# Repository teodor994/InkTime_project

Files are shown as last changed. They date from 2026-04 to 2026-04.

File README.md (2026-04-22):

<h1 align="center">InkTime Watch</h1>

<br>
<br>

This document presents the design and implementation details of the InkTime smartwatch project, covering both the hardware architecture and mechanical integration.

In the following sections, you will find comprehensive documentation including the schematic, PCB layout, component selection, and 3D assembly of the device.

<br> 

## Block Diagram

```text

                                +----------------------+
                                |        USB-C         |
                                |   Power / USB Data   |
                                +----------+-----------+
                                           |
                                           v
                                +----------------------+
                                |   ESD Protection     |
                                |    USBLC6-2SC6Y      |
                                +----------+-----------+
                                           |
                                           v
                                +----------------------+
                                |   Li-Po Charger      |
                                |    BQ25180YBGR       |
                                +----+------------+----+
                                     |            |
                                     |            +--------------------+
                                     |                                 |
                                     v                                 v
                           +-------------------+             +-------------------+
                           |   Li-Po Battery   |             |   Fuel Gauge      |
                           |     LP502030      |<-- I2C ---> |    MAX17048       |
                           +---------+---------+             +-------------------+
                                     |
                                     v
                           +-------------------+
                           | Buck-Boost DC/DC  |
                           |    RT6160AWSC     |
                           +---------+---------+
                                     |
                                   3V3 / VREG
                                     |
        +----------------------------+------------------------------+
        |                            |                              |
        v                            v                              v
+---------------+          +-------------------+          +-------------------+
|   nRF52840    |<--I2C--->|      BMA421       |<--I2C--->|     DRV2605       |
|   BLE MCU     |          |       IMU         |          |   Haptic Driver   |
+-------+-------+          +-------------------+          +---------+---------+
        |                                                              |
        | SPI + GPIO                                                    v
        v                                                      +----------------+
+-------------------+                                          | Vibration Motor|
| 1.54" E-Paper     |                                          |     (Shaker)   |
| via FPC Connector |                                          +----------------+
+-------------------+
        |
        +--> Dedicated E-Paper Power Stage:
             MOSFETs + Schottky Diodes + Inductors + Capacitors

```

## Hardware Functionality

###  Microcontroller

The system is built around a Nordic **nRF52840** SoC  
*(Arm Cortex-M4F @ 64 MHz, 1 MB Flash, 256 kB RAM)*.

This component was chosen because it integrates:
- a **2.4 GHz radio (Bluetooth Low Energy)**
- a **USB 2.0 full-speed controller**

 This allows both:
- wireless communication (BLE)
- USB-C data connectivity  

without requiring any external transceiver.

The MCU operates using two external crystals:
- **32 MHz HF crystal (XC1/XC2)** → CPU + radio
- **32.768 kHz LF crystal (XL1/XL2)** → RTC + low-power timing  

> Accurate timekeeping is critical for a watch, therefore the LFXO is mandatory.

An on-board **2.4 GHz chip antenna (2450AT18B100E)** is:
- placed at the edge of the PCB  
- isolated via a **ground keep-out zone**  

The antenna is connected to the `ANT` pin through a matching network.

---

### Display — E-Paper (SPI)

A reflective **e-paper display** is controlled via the SPI interface:

- `SCK` → P0.02  
- `MOSI` → P0.03  
- `CS` → P0.05  

Additional control signals:
- `EPD_DC` (P0.15) → command/data selection  
- `EPD_RST` (P0.16) → hardware reset  
- `EPD_BUSY` (P0.17) → busy status input  

The display is connected using a **24-pin FPC connector**.

#### Power Optimization
E-paper displays consume power **only during refresh**.

To optimize energy consumption:
- the display power rail is gated using a **PFET**
- controlled by `P1.01`

This allows:
- complete power shutdown between updates  
- significantly extended battery life (days instead of hours)

---

### IMU — BMA421 (I²C)

The **Bosch BMA421** accelerometer provides:
- 3-axis acceleration data  
- built-in **step counting functionality**

Connected via the shared I²C bus.

Interrupt lines:
- `IMU_INT1` → P0.08  
- `IMU_INT2` → P1.08  

These allow:
- wake-up from deep sleep  
- event-driven processing (no polling required)

---

### Haptics — DRV2605 (I²C)

The **TI DRV2605L** controls a vibration motor (LRA/ERM).

Key features:
- I²C configuration interface  
- internal ROM with predefined haptic effects  

The MCU only sends:
> “play effect N” commands  

instead of generating waveforms.

Control signal:
- `HAPTIC_EN` → P0.12  

Allows full shutdown of the driver when idle.

---

### Power Management  
**BQ25180 + MAX17048 + RT6160**

#### USB Input
- USB-C provides **5V input**
- protected by **USBLC6-2SC6Y (ESD protection)**
- includes **5.1 kΩ CC pull-down resistors** → device configured as sink

---

#### Battery Charging — BQ25180
Handles:
- Li-Po charging (CC/CV)
- power path management (USB ↔ battery switching)

Communication:
- I²C interface
- interrupt line: `PMIC_INT` → P0.11  

---

#### Voltage Regulation — RT6160
- Buck-boost converter generating stable **3.3V (VREG)**

Why buck-boost:
- battery range: **3.0V – 4.2V**
- ensures stable output across full discharge cycle

---

#### Fuel Gauge — MAX17048
Provides:
- battery percentage
- voltage monitoring

Uses **ModelGauge algorithm**:
- no current sense resistor required

Communication:
- I²C interface  
- `ALERT` → P1.10 (threshold events)

---

### Inputs — Buttons

Three user buttons connected as:
- `P0.13`
- `P0.14`
- `P1.02`

Characteristics:
- active-low configuration  
- RC debounce  
- internal pull-ups used  

Support:
- GPIOTE interrupts  
- wake-up from System OFF

---

### Shared I²C Bus

All I²C peripherals share the same bus:

Devices:
- BMA421 (IMU)
- MAX17048 (fuel gauge)
- DRV2605L (haptics)
- BQ25180 (charger)

Bus lines:
- `SDA` → P0.06  
- `SCL` → P0.07  

Pull-ups:
- **3.3 kΩ to 3V3**

Operating mode:
- **400 kHz (Fast Mode)**

Sufficient for low-bandwidth sensor communication.

---

### Debug Interface

Programming and debugging via SWD:

- `SWDCLK`
- `SWDIO`
- optional `SWO` → P1.00  

Connector:
- **Tag-Connect TC2030 footprint**

Advantage:
- no bulky header required (important for wearable design)

---

### Expected Capabilities

Based on this hardware, the system supports:

- accurate timekeeping using RTC + LFXO  
- rendering UI on e-paper display  
- step detection & gesture sensing  
- haptic feedback via vibration motor  
- BLE communication with a smartphone  
- USB connectivity for power and data  
- real-time battery monitoring  

The design enables a **low-power wearable device** with multi-day battery life.

## Pinout Table

| Pin | Signal | Direction | Peripheral | Description |
|-----|---|---|---|---|
| P0.02 | SPI_SCK | Output | E-Paper Display | SPI clock |
| P0.03 | SPI_MOSI | Output | E-Paper Display | SPI data out |
| P0.05 | EPD_CS | Output | E-Paper Display | Chip select |
| P0.06 | SDA | Bidir | Fuel Gauge, Charger, IMU, Haptics | Shared I2C data |
| P0.07 | SCL | Output | Fuel Gauge, Charger, IMU, Haptics | Shared I2C clock |
| P0.08 | IMU_INT1 | Input | IMU (BMA421) | Interrupt line 1 |
| P0.11 | PMIC_INT | Input | Charger (BQ25180) | Fault/status interrupt |
| P0.12 | HAPTIC_EN | Output | Haptics (DRV2605) | Driver enable |
| P0.13 | — | Input | Button 1 | User button |
| P0.14 | — | Input | Button 2 | User button |
| P0.15 | EPD_DC | Output | E-Paper Display | Data/command select |
| P0.16 | EPD_RST | Output | E-Paper Display | Display reset |
| P0.17 | EPD_BUSY | Input | E-Paper Display | Busy status |
| P0.18 | RESET | Input | — | System reset |
| P1.00 | SWO | Output | Debug (pad) | SWD trace output |
| P1.01 | — | Output | EPD power gate | EPD power control |
| P1.02 | — | Input | Button 3 | User button |
| P1.08 | IMU_INT2 | Input | IMU (BMA421) | Interrupt line 2 |
| P1.10 | ALERT | Input | Fuel Gauge (MAX17048) | UV/OV alert |
| D+ | D+ | Bidir | USB-C connector | USB data+ |
| D− | D- | Bidir | USB-C connector | USB data− |
| XL1/XL2 | — | — | 32.768 kHz crystal | Low-frequency clock |
| XC1/XC2 | — | — | 32 MHz crystal | High-frequency clock |
| SWDCLK | SWDCLK | Input | Debug (pad) | SWD clock |
| SWDIO | SWDIO | Bidir | Debug (pad) | SWD data |
| ANT | RF | Output | 2.4 GHz antenna | Wireless antenna feed |

## Bill of Materials (BOM)

| Part Name | Qty | Link (Order + Datasheet) |
| :-- | :--: | :--: |
| NRF52840-QIAA-R7 | 1 | [Link](https://jlcpcb.com/partdetail/NordicSemicon-NRF52840_QIAAR7/C1851953) |
| BMA421 | 1 | [Link](https://jlcpcb.com/partdetail/BoschSensortec-BMA421/C5242966) |
| DRV2605YZFR | 1 | [Link](https://jlcpcb.com/partdetail/TexasInstruments-DRV2605YZFR/C81079) |
| BQ25180YBGR | 1 | [Link](https://jlcpcb.com/partdetail/TexasInstruments-BQ25180YBGR/C3682423) |
| MAX17048G+T10 | 1 | [Link](https://jlcpcb.com/partdetail/2777647-MAX17048GT10/C2682616) |
| RT6160AWSC | 1 | [Link](https://jlcpcb.com/partdetail/RichtekTech-RT6160AWSC/C7065276) |
| USBLC6-2SC6Y | 1 | [Link](https://jlcpcb.com/partdetail/TECHPUBLIC-USBLC62SC6Y/C5310974) |
| KH-TYPE-C-16P | 1 | [Link](https://jlcpcb.com/partdetail/Shenzhen_KinghelmElec-KH_TYPE_C16P/C709357) |
| 2450AT18B100E | 1 | [Link](https://jlcpcb.com/partdetail/JohansonDielectrics-2450AT18B100E/C2917717) |
| SI1308EDL-T1-GE3 | 1 | [Link](https://jlcpcb.com/partdetail/VishayIntertech-SI1308EDL_T1GE3/C469327) |
| DMG2305UX-7 | 1 | [Link](https://jlcpcb.com/partdetail/DiodesIncorporated-DMG2305UX7/C150470) |
| 5034802400 | 1 | [Link](https://jlcpcb.com/partdetail/MOLEX-5034802400/C122434) |
| EVPAKE31A | 3 | [Link](https://jlcpcb.com/partdetail/PANASONIC-EVPAKE31A/C569760) |
| NX2016SA-32MHZ-STD-CZS-5 | 1 | [Link](https://jlcpcb.com/partdetail/NDK-NX2016SA_32MHZ_STD_CZS5/C843260) |
| CM8V-T1A-32.768KHZ-9PF-20PPM-TB-QA | 1 | [Link](https://jlcpcb.com/partdetail/C5366546) |
| SDFL1608S100KTF | 1 | [Link](https://jlcpcb.com/partdetail/Sunlord-SDFL1608S100KTF/C1035) |
| SDCL1005C15NJTDF | 1 | [Link](https://jlcpcb.com/partdetail/Sunlord-SDCL1005C15NJTDF/C27143) |
| SDCL1005C3N9STDF | 1 | [Link](https://jlcpcb.com/partdetail/Sunlord-SDCL1005C3N9STDF/C14033) |
| FTC252012SR47MBCA | 1 | [Link](https://jlcpcb.com/partdetail/6763488-FTC252012SR47MBCA/C5832368) |
| 744043680 | 1 | [Link](https://jlcpcb.com/partdetail/WurthElektronik-744043680/C2045671) |
| MBR0530 | 3 | [Link](https://jlcpcb.com/partdetail/78464-MBR0530/C77336) |
| GRM033R61A104KE15D | 5 | [Link](https://jlcpcb.com/partdetail/MurataElectronics-GRM033R61A104KE15D/C76934) |
| GRM155R60J226ME11D | 2 | [Link](https://jlcpcb.com/partdetail/408393-GRM155R60J226ME11D/C415703) |
| GRM155R61H105KE05D | 9 | [Link](https://jlcpcb.com/partdetail/1609005-GRM155R61H105KE05D/C1518208) |
| GRM0335C1H1R0BA01D | 2 | [Link](https://jlcpcb.com/partdetail/MurataElectronics-GRM0335C1H1R0BA01D/C85893) |
| GRM0335C1H101JA01D | 1 | [Link](https://jlcpcb.com/partdetail/MurataElectronics-GRM0335C1H101JA01D/C76922) |
| CGA0402X5R475M250GT | 1 | [Link](https://jlcpcb.com/partdetail/HRE-CGA0402X5R475M250GT/C6119795) |
| CL05A475MP5NRNC | 5 | [Link](https://jlcpcb.com/partdetail/24469-CL05A475MP5NRNC/C23733) |
| CL05A105KA5NQNC | 6 | [Link](https://jlcpcb.com/partdetail/53938-CL05A105KA5NQNC/C52923) |
| CL05A106MQ5NUNC | 3 | [Link](https://jlcpcb.com/partdetail/16204-CL05A106MQ5NUNC/C15525) |
| CC0201KRX5R7BB473 | 1 | [Link](https://jlcpcb.com/partdetail/YAGEO-CC0201KRX5R7BB473/C505465) |
| 0201X104K100NT | 5 | [Link](https://jlcpcb.com/partdetail/270391-0201X104K100NT/C284966) |
| 0201WMF220KTEE | 1 | [Link](https://jlcpcb.com/partdetail/479910-0201WMF220KTEE/C473517) |
| 0201WMJ0000TEE | 3 | [Link](https://jlcpcb.com/partdetail/259867-0201WMJ0000TEE/C270337) |
| 0201WMJ0332TEE | 2 | [Link](https://jlcpcb.com/partdetail/259848-0201WMJ0332TEE/C270318) |
| 0201CG120J500NT | 4 | [Link](https://jlcpcb.com/partdetail/51400-0201CG120J500NT/C50391) |
| CR0201FH5101G | 2 | [Link](https://jlcpcb.com/partdetail/LIZElec-CR0201FH5101G/C100142) |
| CPF0201D10KC1 | 6 | [Link](https://jlcpcb.com/partdetail/TEConnectivity-CPF0201D10KC1/C4187156) |
| UCR006YVPFLR470 | 1 | [Link](https://jlcpcb.com/partdetail/ROHMSemicon-UCR006YVPFLR470/C2089071) |

## Design Details

### Schematic and Components

The reference schematic was carefully reviewed and validated against the datasheets of each individual component. Any inconsistencies identified during this process were analyzed and corrected, most of them originating from outdated reference designs used in the initial schematic.

---

### PCB Layout and Routing

The PCB was designed in accordance with the manufacturing constraints specified by JLCPCB for standard rigid PCB assembly.

A ground pour was implemented on the top layer and connected to the main ground plane using via stitching. Additional manual stitching was applied in sensitive areas, particularly around the antenna feed line, to improve signal integrity.

Teardrops were added to most trace junctions to enhance mechanical reliability. Due to limitations in Fusion when generating teardrops for off-grid or rotated components, some shapes—especially those near the MCU (placed at a 45-degree angle)—were manually refined to ensure proper geometry.

Given the limited available space and the minimum recommended silkscreen text size of 1 mm, an indexed labeling approach was used. Larger components, ICs, and important pads were labeled directly on the silkscreen, while smaller areas rely on the legend.

To ensure mechanical robustness, relatively large internal annular rings were maintained. As a consequence, certain unused pins of the MCU were masked to prevent unintended electrical connections with traces routed underneath.

VIA-in-pad (ViP) technology was used extensively for compact multi-pin SMD components. Any DRC warnings related to ViP clearances were manually reviewed and accepted where appropriate.

Special attention was given to spatial constraints such as:
- antenna keep-out zone
- crystal oscillator trace length
- maximizing distance between the IMU and the shaker motor

Additionally, all decoupling capacitors were placed as close as possible to their respective power pins.

The USB differential pair (D+ and D−) was routed carefully, maintaining approximately equal lengths and minimal spacing between the traces to preserve signal integrity.

---

### 3D Design

Accurate 3D models for all components were integrated into the PCB assembly in order to validate the mechanical design.

The complete enclosure assembly was analyzed to detect any potential mechanical interferences. A possible issue was identified regarding the battery height specified in its datasheet, as the available space in the lower part of the enclosure may be insufficient.

At this stage, the enclosure design was left unchanged, with the intention of validating this aspect during the physical prototyping phase.

## Renders

### PCB 2D
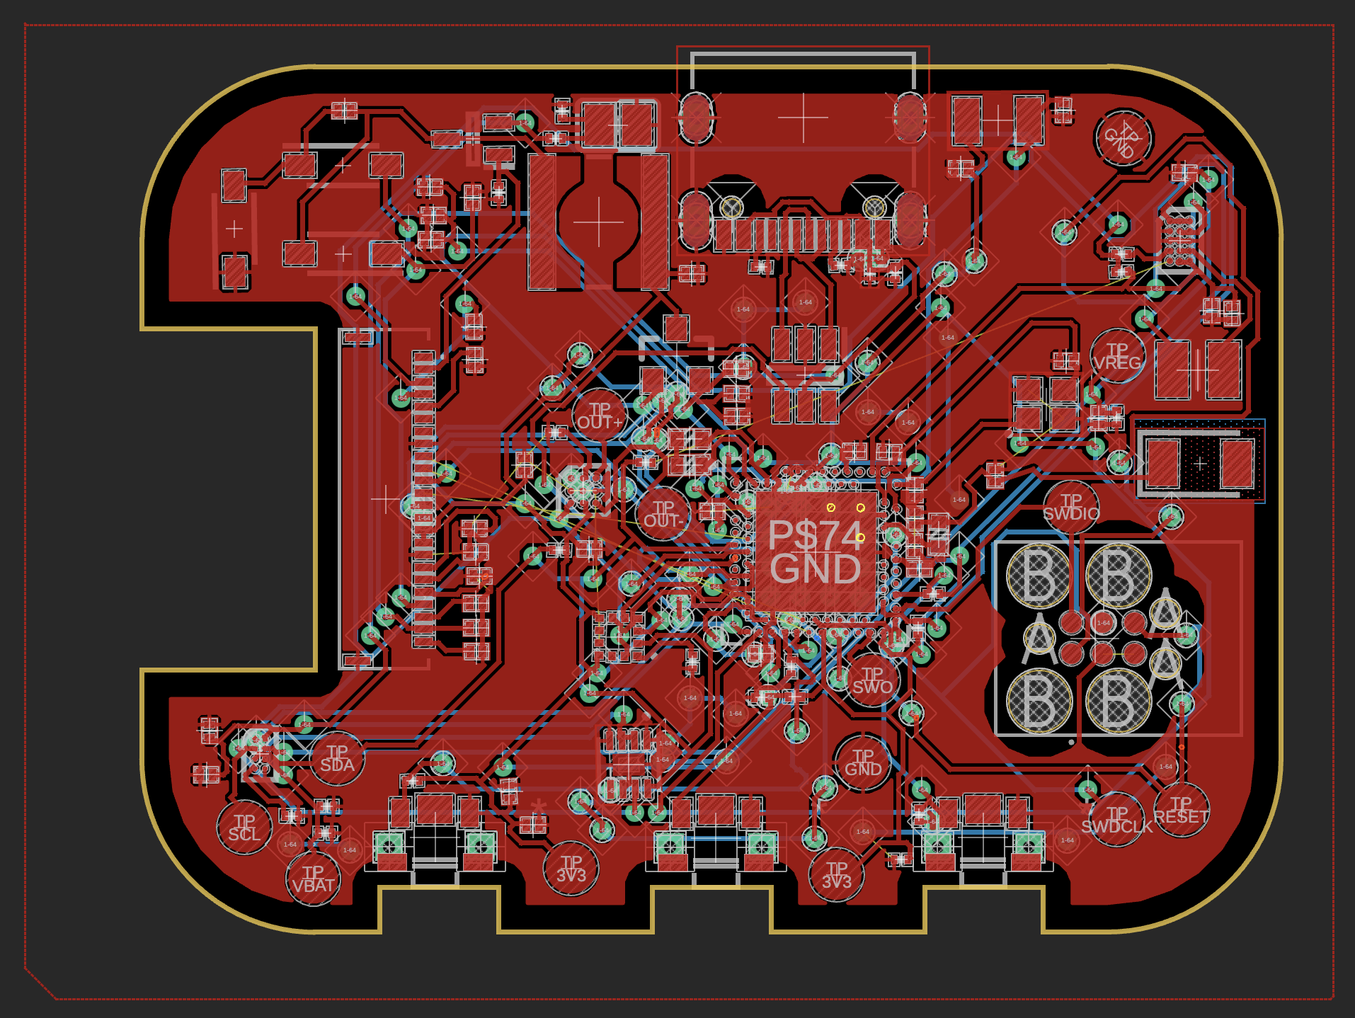
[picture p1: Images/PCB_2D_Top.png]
PCB_2D_Top

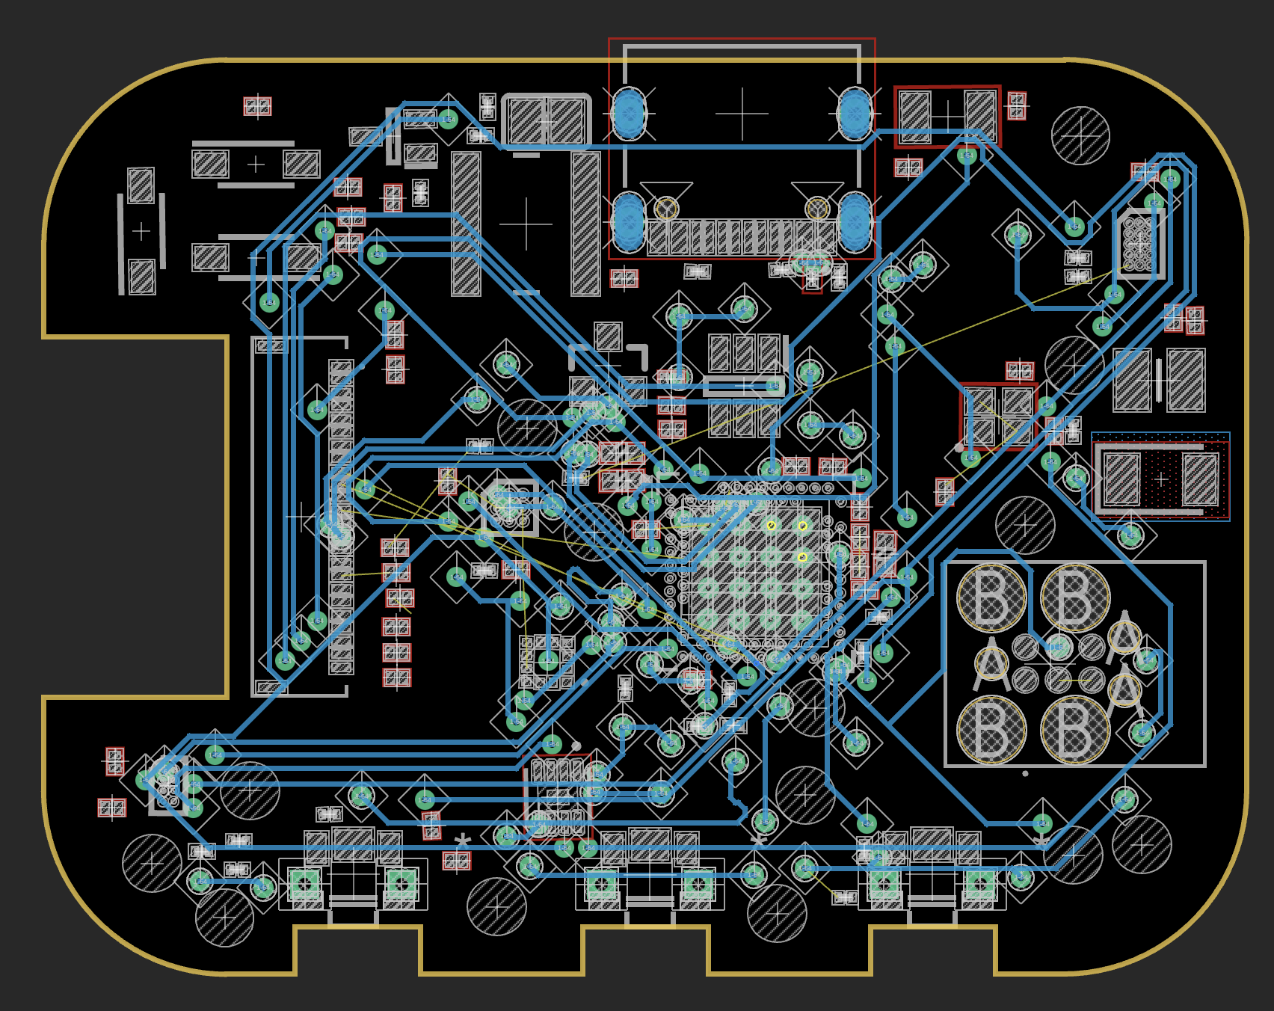
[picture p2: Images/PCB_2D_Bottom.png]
PCB_2D_Bottom


### PCB 3D
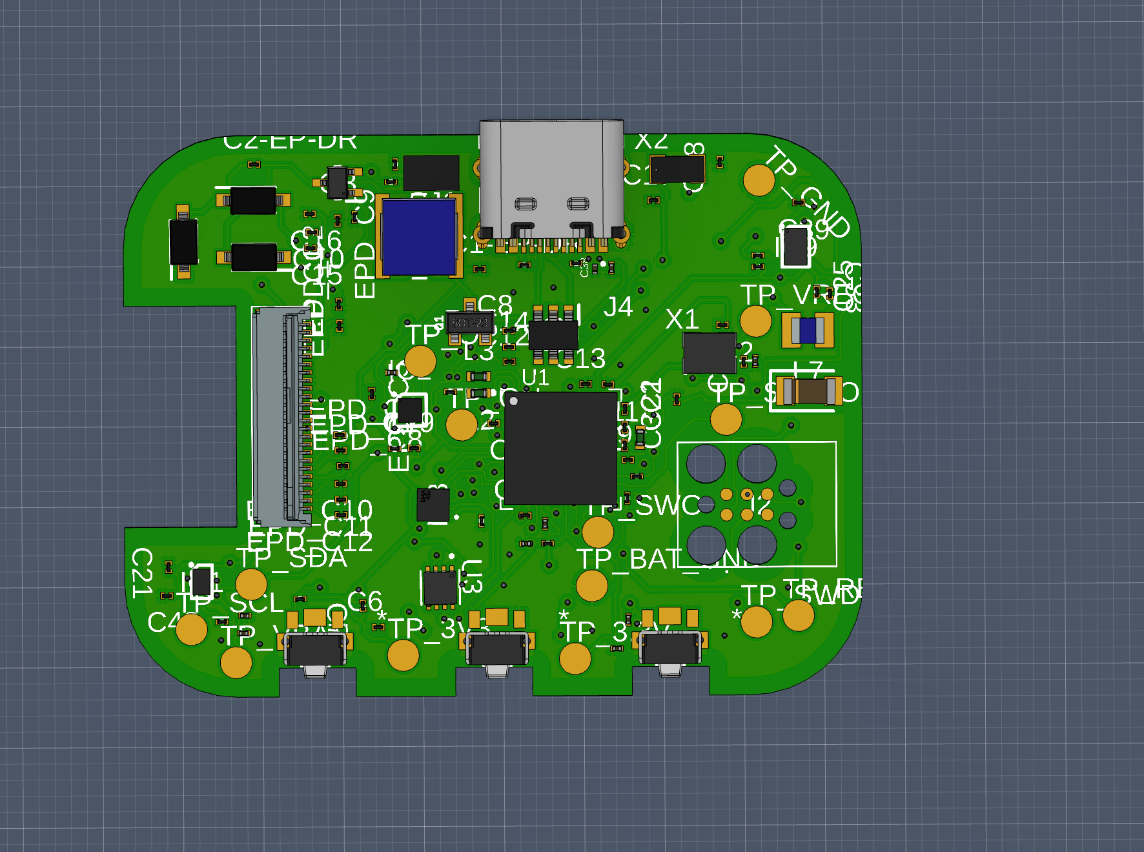
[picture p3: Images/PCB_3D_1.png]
PCB_3D_1

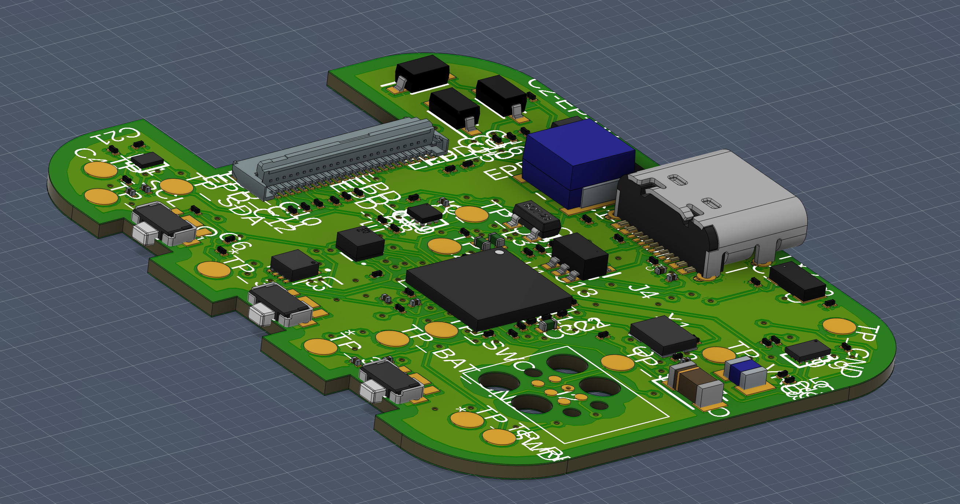
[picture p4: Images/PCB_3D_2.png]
PCB_3D_2


### Assembly
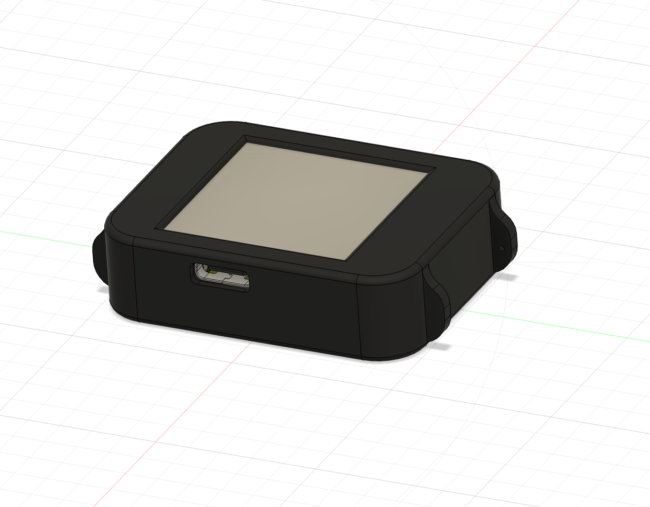
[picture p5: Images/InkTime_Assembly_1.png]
InkTime_Assembly_1

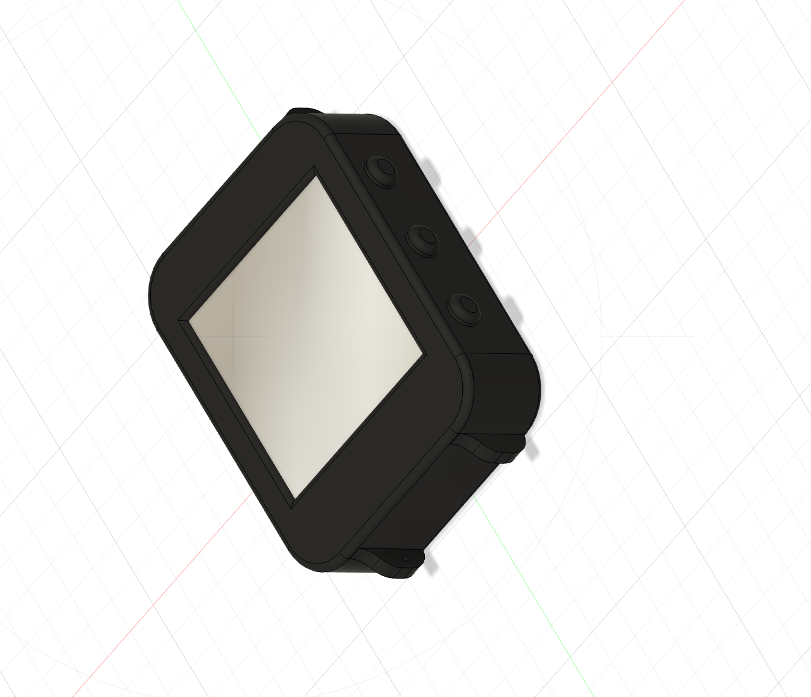
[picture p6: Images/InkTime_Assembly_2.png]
InkTime_Assembly_2


### Exploded View
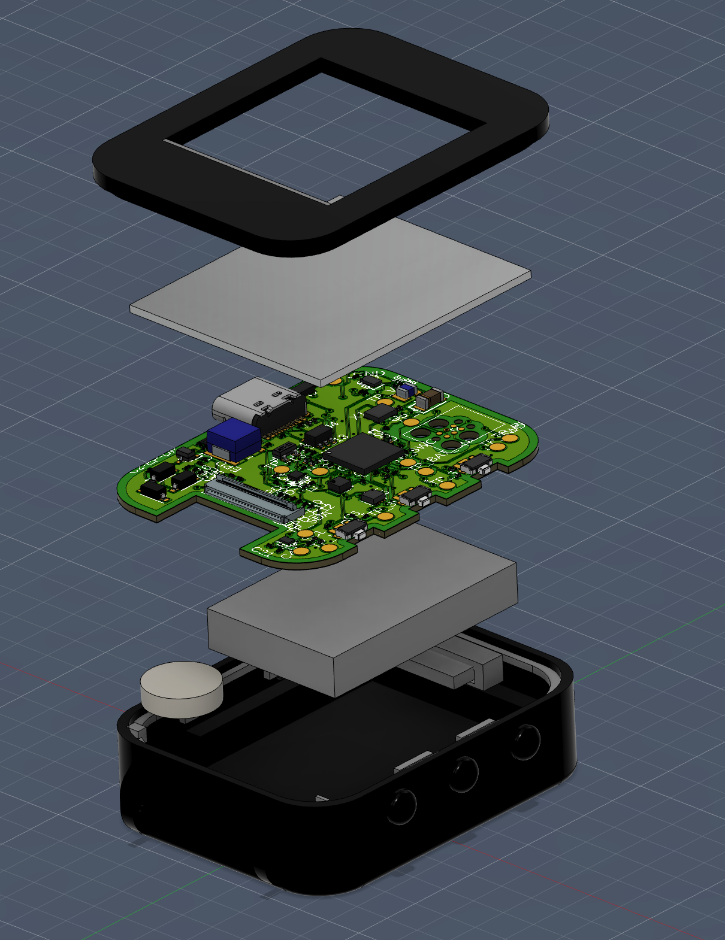
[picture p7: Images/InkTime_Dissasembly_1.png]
InkTime_Dissasembly_1

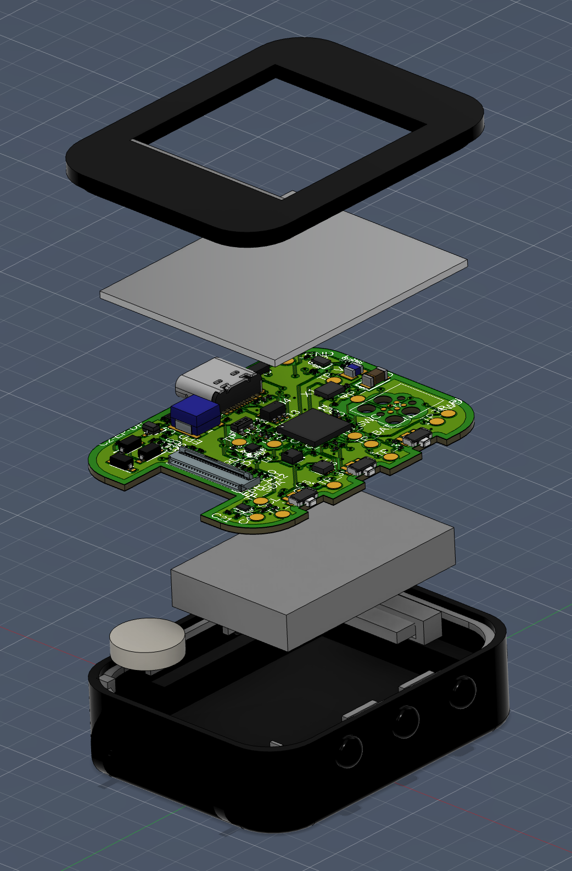
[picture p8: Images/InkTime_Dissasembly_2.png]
InkTime_Dissasembly_2


### Without Display
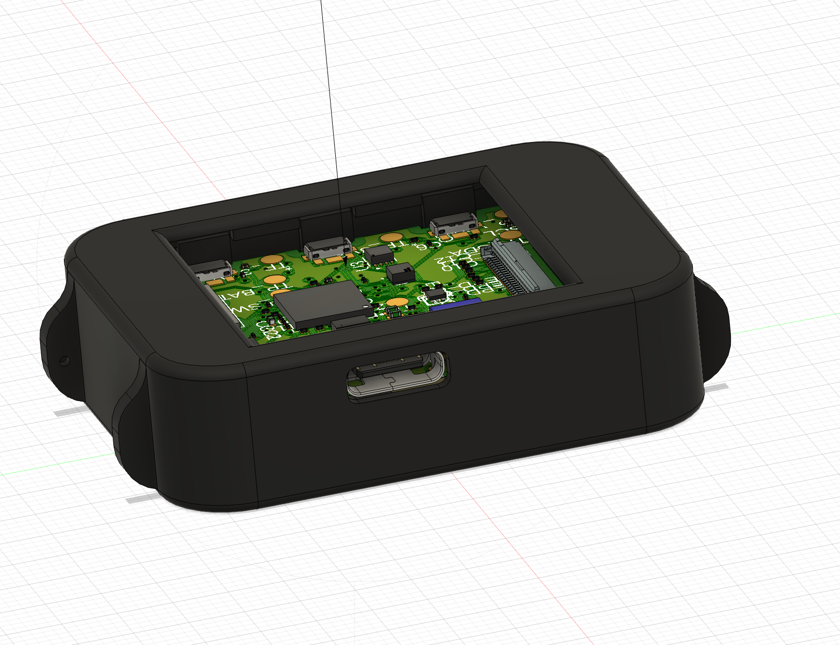
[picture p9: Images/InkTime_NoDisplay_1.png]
InkTime_NoDisplay_1

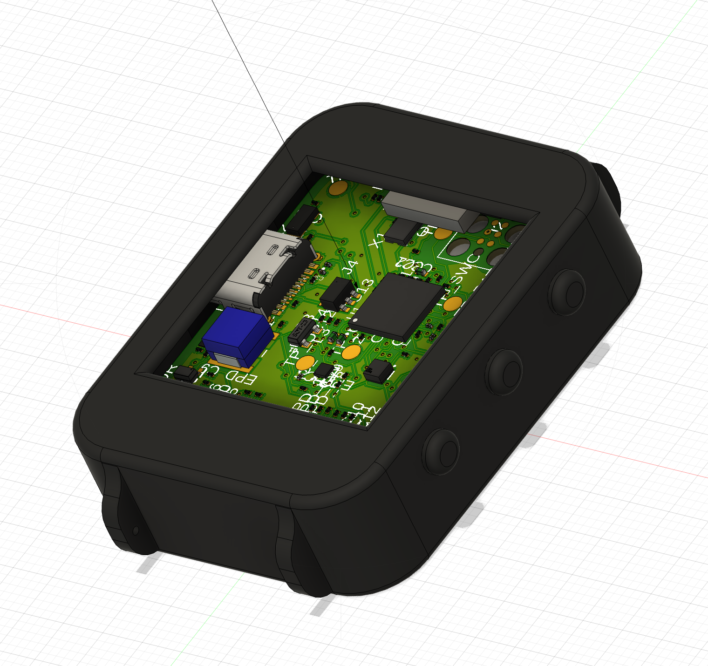
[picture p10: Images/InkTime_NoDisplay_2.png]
InkTime_NoDisplay_2

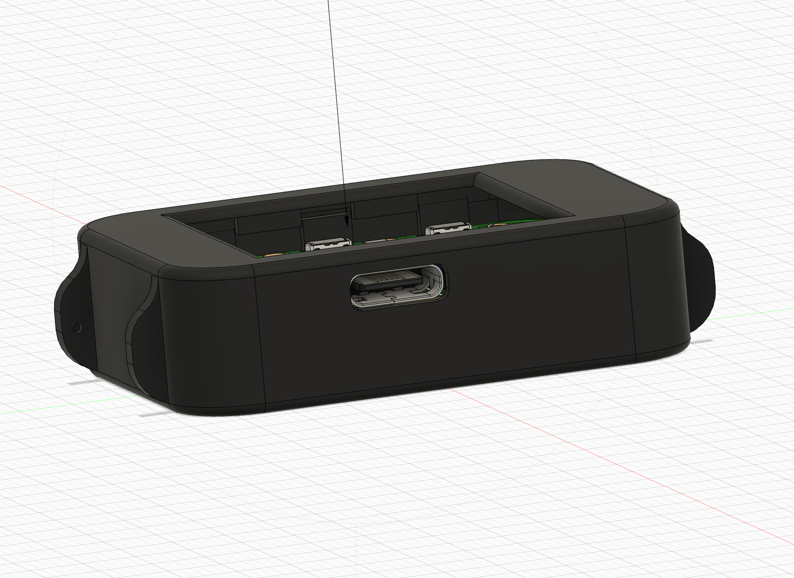
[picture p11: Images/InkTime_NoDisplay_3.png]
InkTime_NoDisplay_3


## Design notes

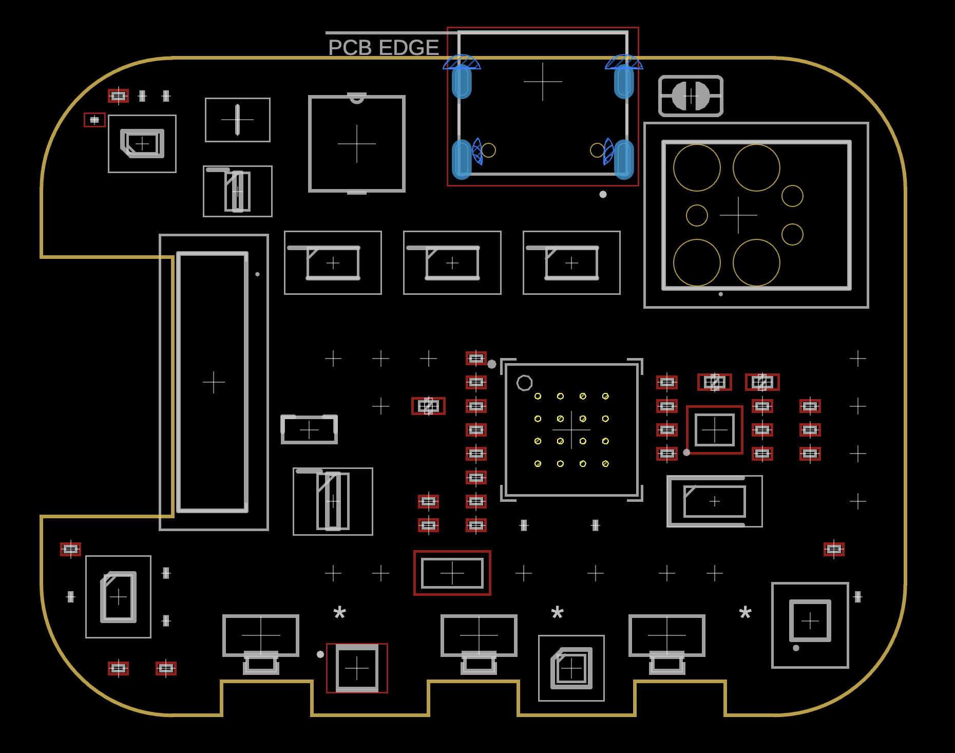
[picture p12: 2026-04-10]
Images/img2btm.png

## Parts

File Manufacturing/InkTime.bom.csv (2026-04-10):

Qty | Value | Device | Package | Parts | Description | ARROW_PART_NUMBER | ARROW_PRICE-STOCK | AVAILABILITY | CHECK_PRICES | COPYRIGHT | DESCRIPTION | DIGI-KEY_PART_NUMBER_1 | DIGI-KEY_PART_NUMBER_2 | DIGI-KEY_PART_NUMBER_3 | HEIGHT | JLCPCB | MANUFACTURER_NAME | MANUFACTURER_PART_NUMBER | MF | MFR_NAME | MOUSER_PART_NUMBER | MOUSER_PRICE-STOCK | MP | PACKAGE | POPULARITY | PRICE | PROD_ID | PURCHASE-URL | SNAPEDA_LINK | STATUS | TP_SIGNAL_NAME | VALUE
1 |  | ESP32_C6_LIBRARY_7_JUMPER_SJ | ESP32_C6_LIBRARY_7_JUMPER_SJ | SJ1 | SMD solder JUMPER |  |  |  |  |  |  |  |  |  |  |  |  |  |  |  |  |  |  |  | 3
3 | 0 | CPF0201D7K68C1_CPF0201D7K68C1 | CPF0201D7K68C1_0201 | R2, R3, R4 | 7.68k 0201 Thin Film Surface Mount Fixed Resistor +/-0.5% 0.031W CPF0201D7K68C1
4 | 0.1uF | GRM011R60J152KE01L_1_GRM011R60J152KE01L | GRM011R60J152KE01L_1_0201 | C23, C27, C34, C42 | Check availability
1 | 0.1uF/50V | NORDIC_NRF_3_CAPACITOR_0201_L | NORDIC_NRF_3_RESC0201_L | EPD_C5 | Generic chip capacitor
1 | 0.47 | CPF0201D7K68C1_CPF0201D7K68C1 | CPF0201D7K68C1_0201 | R1_EP_DR | 7.68k 0201 Thin Film Surface Mount Fixed Resistor +/-0.5% 0.031W CPF0201D7K68C1
1 | 1.0µF | NORDIC_NRF_3_CAPACITOR_0201_L | NORDIC_NRF_3_RESC0201_L | C15 | Generic chip capacitor
5 | 100nF | NORDIC_NRF_3_CAPACITOR_0201_L | NORDIC_NRF_3_RESC0201_L | C5, C7, C8, C12, C19 | Generic chip capacitor
1 | 100pF | NORDIC_NRF_3_CAPACITOR_0201_L | NORDIC_NRF_3_RESC0201_L | C11 | Generic chip capacitor
3 | 10K | CPF0201D7K68C1_CPF0201D7K68C1 | CPF0201D7K68C1_0201 | R2_EP_DR, R9, R_PWR_EPD | 7.68k 0201 Thin Film Surface Mount Fixed Resistor +/-0.5% 0.031W CPF0201D7K68C1
3 | 10k | CPF0201D7K68C1_CPF0201D7K68C1 | CPF0201D7K68C1_0201 | R5, R7, R8 | 7.68k 0201 Thin Film Surface Mount Fixed Resistor +/-0.5% 0.031W CPF0201D7K68C1
3 | 10uF | NORDIC_NRF_3_CAPACITOR_0201_L | NORDIC_NRF_3_RESC0201_L | C1-EP-DR, C24, C39 | Generic chip capacitor
1 | 10µH | NORDIC_NRF_2_INDUCTOR_0402_L | NORDIC_NRF_2_RESC0402_L | L2 | Generic chip inductor
4 | 12pF | NORDIC_NRF_3_CAPACITOR_0201_L | NORDIC_NRF_3_RESC0201_L | C1, C2, C17, C18 | Generic chip capacitor
1 | 15nH | NORDIC_NRF_2_INDUCTOR_0402_L | NORDIC_NRF_2_RESC0402_L | L3 | Generic chip inductor
2 | 1pF | NORDIC_NRF_3_CAPACITOR_0201_L | NORDIC_NRF_3_RESC0201_L | C3, C4 | Generic chip capacitor
5 | 1uF | GRM011R60J152KE01L_1_GRM011R60J152KE01L | GRM011R60J152KE01L_1_0201 | C29, C30, C31, C32, C37 | Check availability
1 | 1uF | GRM011R60J152KE01L_2_GRM011R60J152KE01L | GRM011R60J152KE01L_2_CAPC0201X13N | C38 | Check availability |  |  | In Stock | https://www.snapeda.com/parts/GRM011R60J152KE01L/Murata/view-part/?ref=eda |  | SMD Capacitor X5R(EIA) with Capacitance: 1500pF Tol. 10%. Rated Voltage: 6.3Vdc |  |  |  |  |  |  |  | Murata |  |  |  | GRM011R60J152KE01L | 0201 Murata |  | None |  |  | https://www.snapeda.com/parts/GRM011R60J152KE01L/Murata/view-part/?ref=snap
9 | 1uF/50V | NORDIC_NRF_3_CAPACITOR_0201_L | NORDIC_NRF_3_RESC0201_L | EPD_C1, EPD_C2, EPD_C6, EPD_C7, EPD_C8, EPD_C9, EPD_C10, EPD_C11, EPD_C12 | Generic chip capacitor
1 | 2.2 | CPF0201D7K68C1_CPF0201D7K68C1 | CPF0201D7K68C1_0201 | R_TYPE_SEL | 7.68k 0201 Thin Film Surface Mount Fixed Resistor +/-0.5% 0.031W CPF0201D7K68C1
3 | 2025-10-22_07-23-44_LIBRARY_EVP-AKE31ASW_EVP-AKE31A_PAN | 2025-10-22_07-23-44_LIBRARY_EVP-AKE31ASW_EVP-AKE31A_PAN | 2025-10-22_07-23-44_LIBRARY_SW_EVP-AKE31A_PAN | SW_DN, SW_ENT, SW_UP |  |  |  |  |  | Copyright (C) 2025 Ultra Librarian. All rights reserved. |  | P123437TR-ND | P123437CT-ND | P123437DKR-ND |  |  | Panasonic | EVP-AKE31A
1 | 20V/4.2A/52mΩ/1.4W | ESP32_C6_LIBRARY_4_ESP32_WROVER_SPARKFUN-DISCRETESEMI_MOSFET_PCH-DMG2305UX-7 | ESP32_C6_LIBRARY_4_ESP32_C6_LIBRARY_4_ESP32_C6_LIBRARY_4_ESP32_C6_LIBRARY_4_ESP32_WROVER_SPARKFUN-DISCRETESEMI_SOT23-3 | Q1 | P-channel MOSFETs |  |  |  |  |  |  |  |  |  |  |  |  |  |  |  |  |  |  |  |  |  | TRAN-14388 |  |  |  |  | 20V/4.2A/52mΩ/1.4W
2 | 22uF | NORDIC_NRF_3_CAPACITOR_0201_L | NORDIC_NRF_3_RESC0201_L | C25, C33 | Generic chip capacitor
1 | 2450AT18B100E | 2450AT18B100E_2450AT18B100E | 2450AT18B100E_ANTC3216X140N | ANT1 | Antennas 2.45GHz ANTENNA | 2450AT18B100E | https://www.arrow.com/en/products/2450at18b100e/johanson-dielectrics?utm_currency=USD&region=nac |  |  |  | Antennas 2.45GHz ANTENNA |  |  |  | 1.4mm |  | JOHANSON TECHNOLOGY | 2450AT18B100E |  |  | 609-2450AT18B100E | https://www.mouser.co.uk/ProductDetail/Johanson-Technology/2450AT18B100E?qs=yCnrNFeXz%252Bh5MFsFIXGZGA%3D%3D
1 | 3.9nH | NORDIC_NRF_2_INDUCTOR_0402_L | NORDIC_NRF_2_RESC0402_L | L1 | Generic chip inductor
1 | 32.768kHz | NORDIC_NRF_1_XTAL_32KHZ | NORDIC_NRF_1_XTAL_3215_N | X2
1 | 32MHz | NORDIC_NRF_XTAL_32MHZ | NORDIC_NRF_BT-XTAL_2016_N | X1
2 | 3K3 | CPF0201D7K68C1_CPF0201D7K68C1 | CPF0201D7K68C1_0201 | R17, R18 | 7.68k 0201 Thin Film Surface Mount Fixed Resistor +/-0.5% 0.031W CPF0201D7K68C1
1 | 4.7uF | NORDIC_NRF_3_CAPACITOR_0201_L | NORDIC_NRF_3_RESC0201_L | C43 | Generic chip capacitor
1 | 4.7uF/25V | NORDIC_NRF_3_CAPACITOR_0201_L | NORDIC_NRF_3_RESC0201_L | C2-EP-DR | Generic chip capacitor
4 | 4.7µF | NORDIC_NRF_3_CAPACITOR_0201_L | NORDIC_NRF_3_RESC0201_L | C6, C14, C20, C21 | Generic chip capacitor
1 | 47nF | NORDIC_NRF_3_CAPACITOR_0201_L | NORDIC_NRF_3_RESC0201_L | C16 | Generic chip capacitor
1 | 503480-2400 | 503480-2400_503480-2400 | 503480-2400_5034802400 | J1 | FFC & FPC Connectors 0.5mm FPC RA SMT Dual Contact 24Ckt |  |  |  |  |  | FFC & FPC Connectors 0.5mm FPC RA SMT Dual Contact 24Ckt |  |  |  | 1.87mm |  | Molex | 503480-2400 |  |  | 538-503480-2400 | https://www.mouser.co.uk/ProductDetail/Molex/503480-2400?qs=OAhjpuo3Vu7efIoxFh9AOw%3D%3D
2 | 5K1 | CPF0201D7K68C1_CPF0201D7K68C1 | CPF0201D7K68C1_0201 | R1_USB, R2_USB | 7.68k 0201 Thin Film Surface Mount Fixed Resistor +/-0.5% 0.031W CPF0201D7K68C1
1 | 68uH | ESP32_C6_LIBRARY_2_744043680IND_4828-WE-TPC_WRE | ESP32_C6_LIBRARY_2_IND_4828-WE-TPC_WRE | L5 |  |  |  |  |  | Copyright (C) 2024 Ultra Librarian. All rights reserved. |  |  |  |  |  |  |  | 744043680 |  | Wurth Electronics
1 | 820pF | NORDIC_NRF_3_CAPACITOR_0201_L | NORDIC_NRF_3_RESC0201_L | C9 | Generic chip capacitor |  |  |  |  |  |  |  |  |  |  |  |  |  |  |  |  |  |  |  |  |  |  |  |  | N.C.
1 | BMA421 | BMA423_BMA423 | BMA423_BMA423 | IC3 | Accelerometers Triaxial low-g 12bit Acceleration Sensor | BMA423 | https://www.arrow.com/en/products/bma423/bosch |  |  |  | Accelerometers Triaxial low-g 12bit Acceleration Sensor |  |  |  | 1mm |  | BOSCH | BMA423 |  |  | 262-BMA423 | https://www.mouser.co.uk/ProductDetail/Bosch-Sensortec/BMA423?qs=HXFqYaX1Q2xC%252BSgeGoX3mg%3D%3D
1 | BQ25180YBGR | BQ25180YBGR_BQ25180YBGR | BQ25180YBGR_BGA8C40P2X4_100X155X50 | IC1 | Charger IC Lithium Ion/Polymer, Lithium Iron Phosphate 8-DSBGA (1.6x1.1) | BQ25180YBGR | https://www.arrow.com/en/products/bq25180ybgr/texas-instruments?utm_currency=USD&region=nac |  |  |  | Charger IC Lithium Ion/Polymer | Lithium Iron Phosphate 8-DSBGA (1.6x1.1) |  |  |  | 0.5mm |  | Texas Instruments | BQ25180YBGR |  |  | 595-BQ25180YBGR | https://www.mouser.co.uk/ProductDetail/Texas-Instruments/BQ25180YBGR?qs=doiCPypUmgEWjAK%252BJAX6Tw%3D%3D
1 | DRV2605YZFR | DRV2605YZFR_DRV2605YZFR | DRV2605YZFR_BGA9C50P3X3_144X144X62 | IC2 | Haptic Driver for ERM/LRA with Built-In Library and Smart Loop Architecture | DRV2605YZFR | https://www.arrow.com/en/products/drv2605yzfr/texas-instruments?region=nac |  |  |  | Haptic Driver for ERM/LRA with Built-In Library and Smart Loop Architecture |  |  |  | 0.625mm |  | Texas Instruments | DRV2605YZFR
1 | FTC252012SR47MBCA | MLP2016SR47MT0S1_FTC252012SR47MBCA | MLP2016SR47MT0S1_INDC2016X100N | L7 | SMD / SMT Inductors (Coils), L=0.47?H, L x W x T : |  |  |  |  |  | SMD / SMT Inductors (Coils) | L=0.47?H | L x W x T : |  |  |  | 1mm | https://jlcpcb.com/partdetail/6763488-FTC252012SR47MBCA/C5832368 | TDK | FTC252012SR47MBCA
14 | HECTOR_WATCH_1_TPTP20R | HECTOR_WATCH_1_TPTP20R | HECTOR_WATCH_1_TP20R | TP_3.3V, TP_3V3, TP_BAT_GND, TP_GND, TP_ON, TP_OP, TP_RESET, TP_SCL, TP_SDA, TP_SWDCLK, TP_SWDIO, TP_SWO, TP_VBAT, TP_VREG | Test pad |  |  |  |  |  |  |  |  |  |  |  |  |  |  |  |  |  |  |  | 2
1 | KH-TYPE-C-16P | KH-TYPE-C-16P_KH-TYPE-C-16P | KH-TYPE-C-16P_KINGHELM_KH-TYPE-C-16P | J4 | Check availability |  |  | Not in stock | https://www.snapeda.com/parts/KH-TYPE-C-16P/Kinghelm/view-part/?ref=eda |  |  |  |  |  |  |  |  |  | kinghelm |  |  |  | KH-TYPE-C-16P | None |  | None |  |  | https://www.snapeda.com/parts/KH-TYPE-C-16P/Kinghelm/view-part/?ref=snap
1 | MAX17048G+T10 | ESP32_C6_LIBRARY_MAX17048G+T10 | ESP32_C6_LIBRARY_SON50P200X200X80-9N | U3 | Check availability |  |  | In Stock | https://www.snapeda.com/parts/MAX17048G+T10/Analog+Devices/view-part/?ref=eda |  | 3µA 1-Cell/2-Cell Fuel Gauge with ModelGauge |  |  |  |  |  |  |  | Analog Devices |  |  |  | MAX17048G+T10 | TDFN-8 Maxim |  | None |  | https://www.snapeda.com/api/url_track_click_mouser/?unipart_id=329239&manufacturer=Analog Devices&part_name=MAX17048G+T10&search_term=None | https://www.snapeda.com/parts/MAX17048G+T10/Analog+Devices/view-part/?ref=snap
3 | MBR0530 | ESP32_C6_LIBRARY_5_MBR0530 | ESP32_C6_LIBRARY_5_SOD3716X135N | D2, D4, D5 | ON SEMICONDUCTOR - MBR0530 - DIODE, SCHOTTKY, 0.5A, 30V, SOD-123 |  |  | In Stock | https://www.snapeda.com/parts/MBR0530/Onsemi/view-part/?ref=eda |  | Diode Schottky 30 V 500mA Surface Mount SOD-123 |  |  |  |  |  |  |  | ON Semiconductor |  |  |  | MBR0530 | SOD-123-2 ON Semiconductor |  | None |  | https://www.snapeda.com/api/url_track_click_mouser/?unipart_id=179458&manufacturer=ON Semiconductor&part_name=MBR0530&search_term=None | https://www.snapeda.com/parts/MBR0530/Onsemi/view-part/?ref=snap
3 | N.C. | NORDIC_NRF_3_CAPACITOR_0201_L | NORDIC_NRF_3_RESC0201_L | C10, C13, C22 | Generic chip capacitor
1 | NRF52840_QF | NORDIC_NRF_4_NRF52840_QF | NORDIC_NRF_4_AQFN50P700X700X85_HS-74N | U1 | nRF52840
1 | RT6160AWSC | RT6160AWSC_RT6160AWSC | RT6160AWSC_BGA15C40P3X5_140X230X60 | IC9 | Buck-Boost Regulator Positive Output Step-Up/Step-Down I2C DC-DC Controller IC 15-WL-CSP (BSC) (1.4x2.3) |  |  |  |  |  | Buck-Boost Regulator Positive Output Step-Up/Step-Down I2C DC-DC Controller IC 15-WL-CSP (BSC) (1.4x2.3) |  |  |  | 0.6mm |  | RICHTEK | RT6160AWSC |  |  | 835-RT6160AWSC | https://www.mouser.co.uk/ProductDetail/Richtek/RT6160AWSC?qs=amGC7iS6iy%2FLd9PSoixZXQ%3D%3D
1 | SI1308EDL-T1-GE3 | ESP32_C6_LIBRARY_6_SI1308EDL-T1-GE3 | ESP32_C6_LIBRARY_6_SOT65P210X110-3N | Q3 | MOSFET N-Ch 30V 1.5A TrenchFET SC70 Vishay Si1308EDL-T1-GE3 N-channel MOSFET Transistor, 1.5 A, 30 V, 3-Pin SC-70 |  |  | In Stock | https://www.snapeda.com/parts/SI1308EDL-T1-GE3/Vishay+Siliconix/view-part/?ref=eda |  | Si1308EDL-T1-GE3 N-channel MOSFET Transistor | 1.5 A | 30 V | 3-Pin SC-70 | Siliconix / Vishay SI1308EDL-T1-GE3 |  |  |  |  |  |  |  | Vishay Siliconix |  |  |  | SI1308EDL-T1-GE3 | SOT-323 Vishay Semiconductor |  | None |  | https://www.snapeda.com/api/url_track_click_mouser/?unipart_id=274603&manufacturer=Vishay Siliconix&part_name=SI1308EDL-T1-GE3&search_term=None | https://www.snapeda.com/parts/SI1308EDL-T1-GE3/Vishay+Siliconix/view-part/?ref=snap
1 | TC2030-IDC | TC2030-IDC_TC2030-IDC | TC2030-IDC_TC2030IDC | J2 | CABLE ADAPTER 6 POS |  |  |  |  |  | CABLE ADAPTER 6 POS |  |  |  | 19mm |  | Tag Connect | TC2030-IDC
1 | USBLC6-2SC6Y | ESP32_C6_LIBRARY_3_USBLC6-2SC6Y | ESP32_C6_LIBRARY_3_SOT95P280X145-6N | D3 | Low Cap. ESD Protection Auto SOT-23-6 STMicroelectronics USBLC6-2SC6Y, Dual Uni-Directional TVS Diode Array, 6-Pin SOT-23 |  |  | In Stock | https://www.snapeda.com/parts/USBLC6-2SC6Y/STMicroelectronics/view-part/?ref=eda |  | 17V Clamp 5A (8/20µs) Ipp Tvs Diode Surface Mount SOT-23-6 |  |  |  |  |  |  |  | STMicroelectronics |  |  |  | USBLC6-2SC6Y | SOT-23-6 STMicroelectronics |  | None |  |  | https://www.snapeda.com/parts/USBLC6-2SC6Y/STMicroelectronics/view-part/?ref=snap

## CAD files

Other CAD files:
Mechanical/InkTime3D - FinalAssembly.f3z
Mechanical/InkTime3D - exploded view.f3z

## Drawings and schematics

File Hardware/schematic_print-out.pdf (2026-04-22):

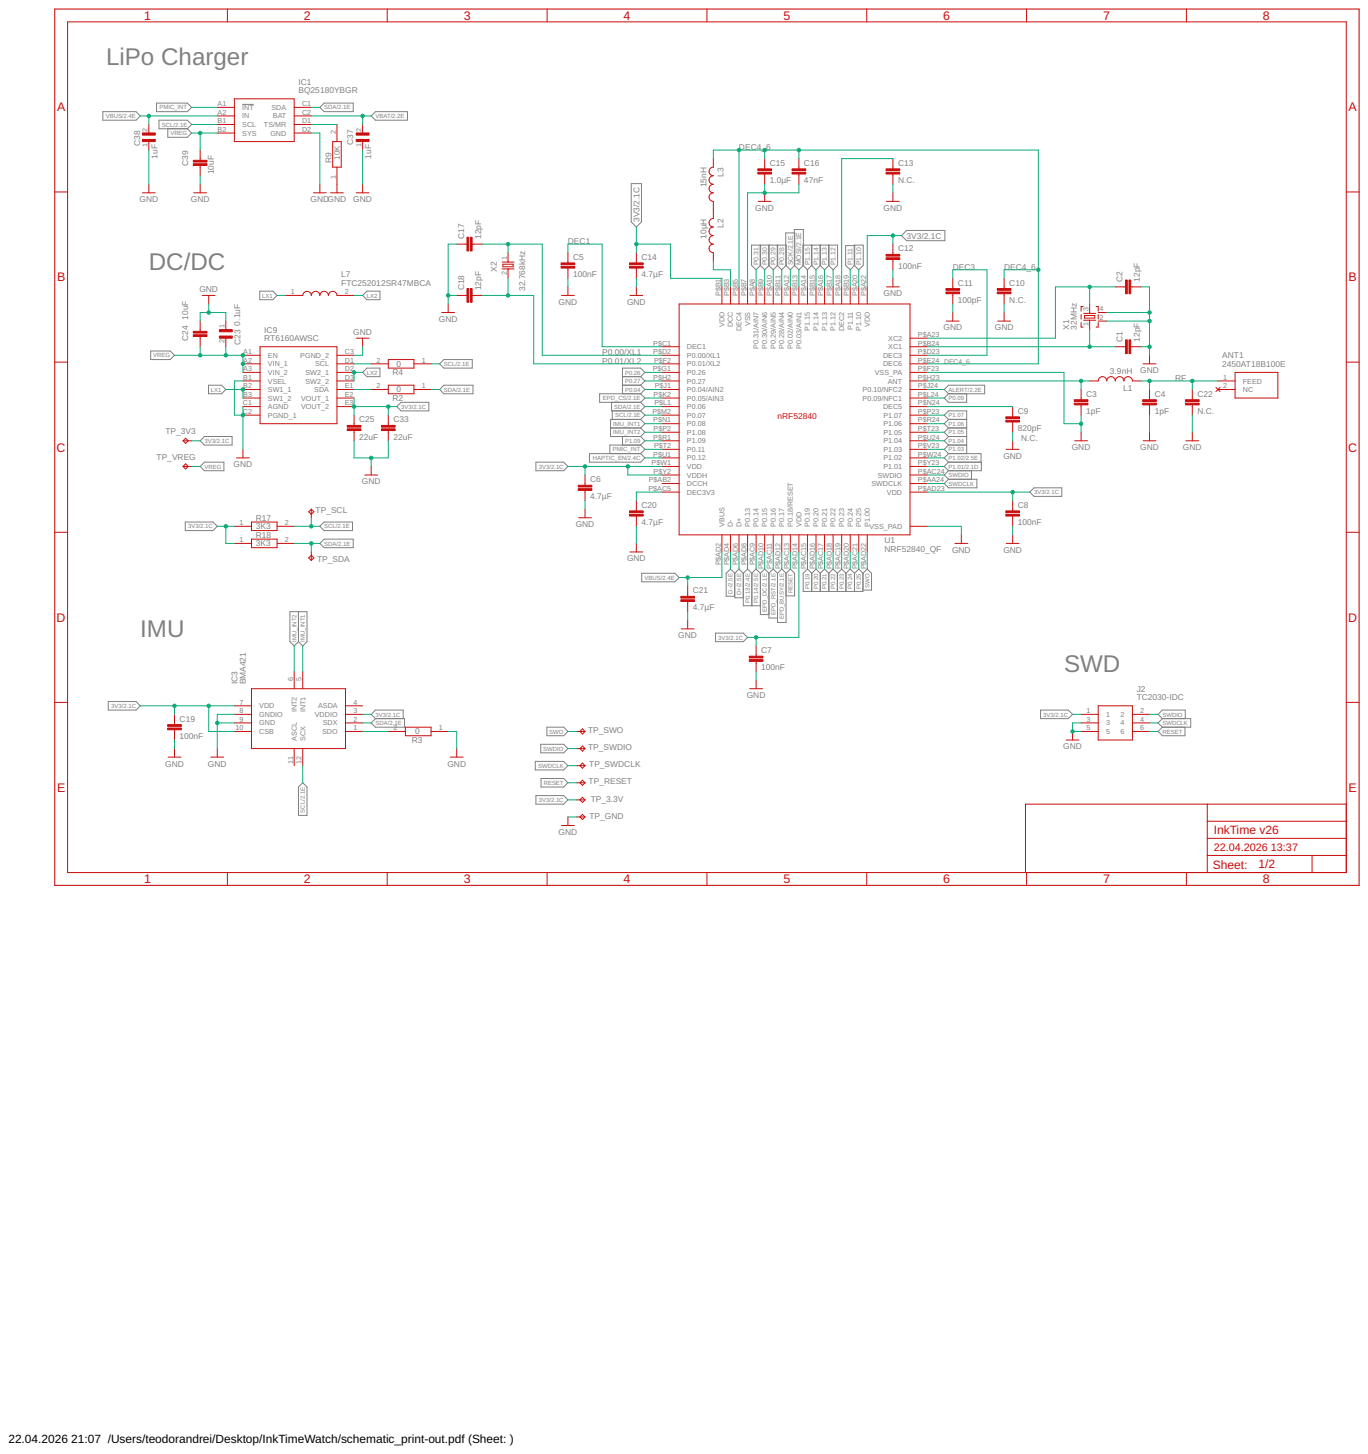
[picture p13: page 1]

22.04.2026 21:07 /Users/teodorandrei/Desktop/InkTimeWatch/schematic_print-out.pdf (Sheet: )

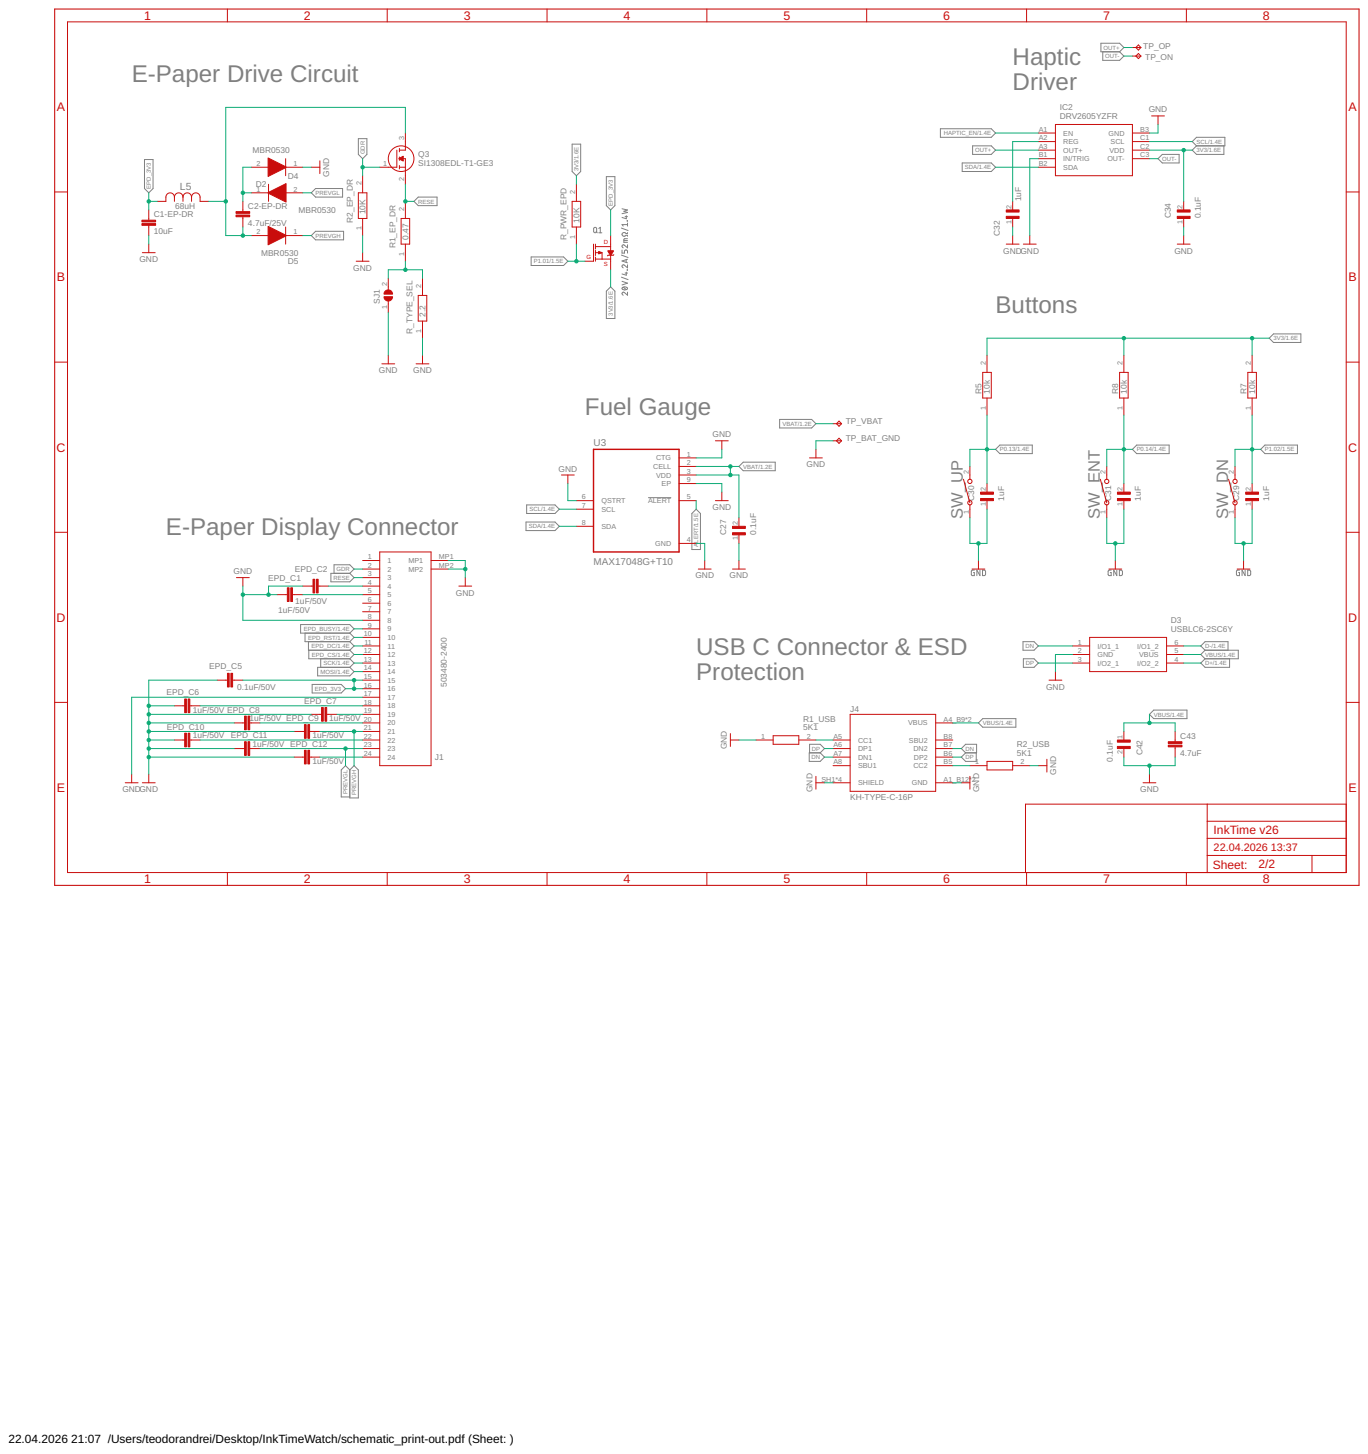
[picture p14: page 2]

1uF/50V EPD_C8 | 19

EPD_C7 18

EPD_C10 | | 21
1uF/50V EPD_C11 | 1uF/50V | 22

1uF/50V EPD_C12 | 23

22.04.2026 21:07 /Users/teodorandrei/Desktop/InkTimeWatch/schematic_print-out.pdf (Sheet: )

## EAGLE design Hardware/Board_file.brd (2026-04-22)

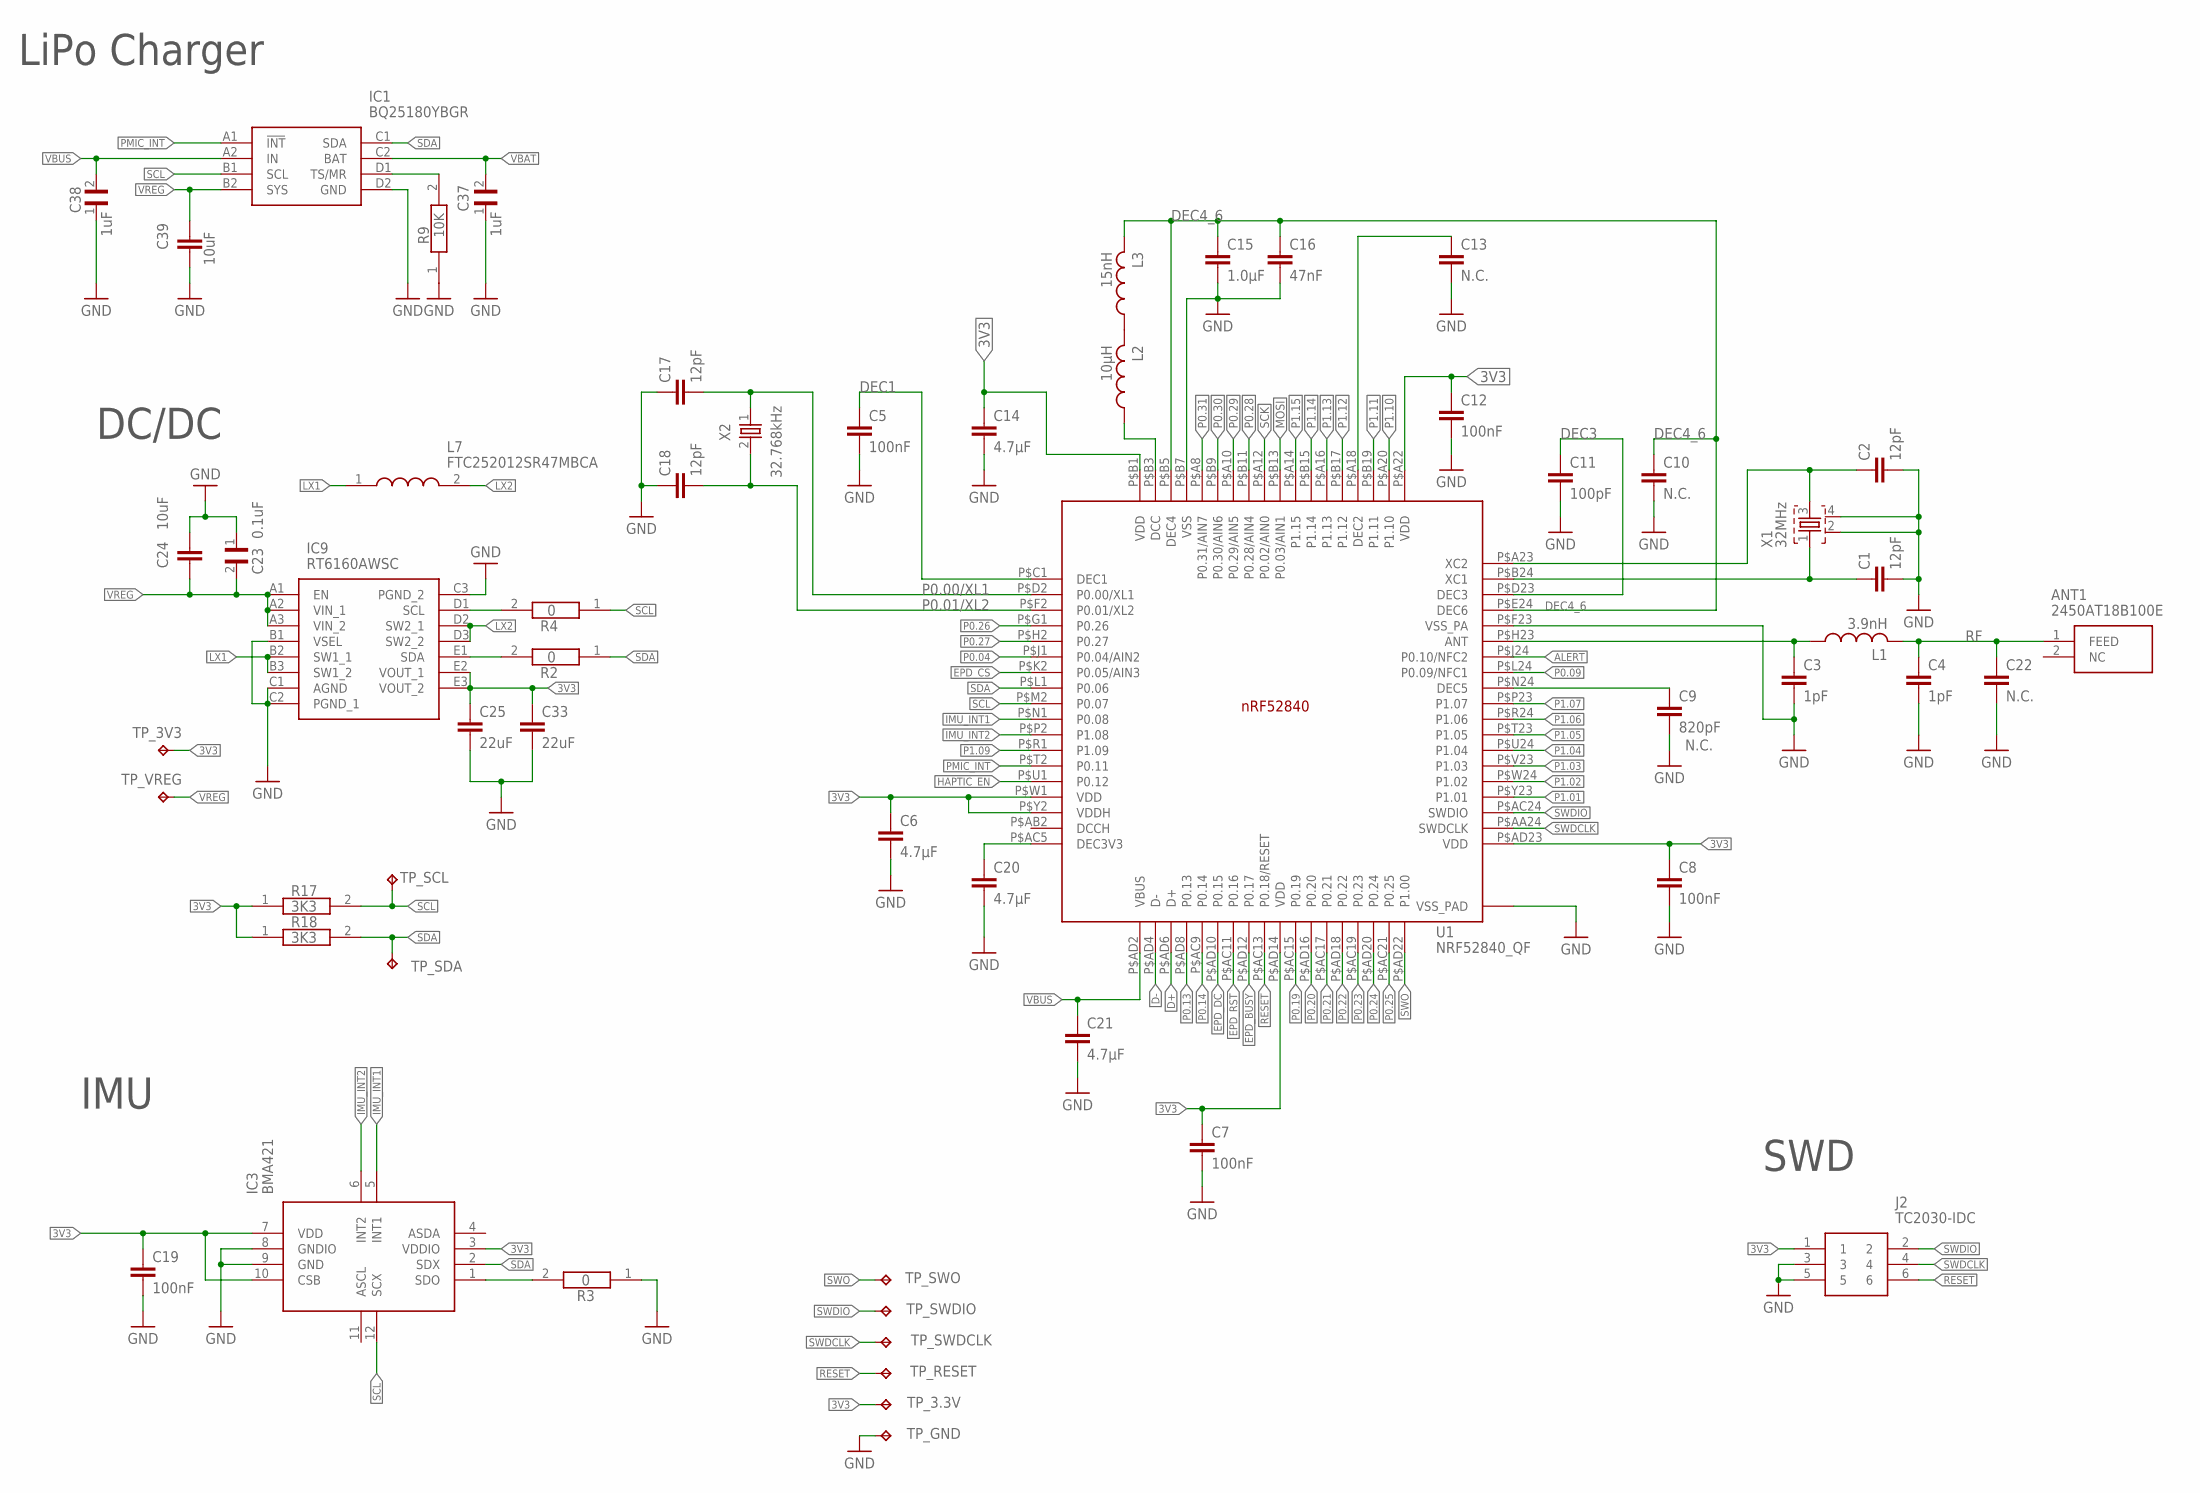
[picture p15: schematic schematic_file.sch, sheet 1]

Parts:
ANT1: 2450AT18B100E; 2450AT18B100E_ANTC3216X140N
C1, C2, C17, C18: 12pF; NORDIC_NRF_3_RESC0201_L
C3, C4: 1pF; NORDIC_NRF_3_RESC0201_L
C5, C7, C8, C12, C19: 100nF; NORDIC_NRF_3_RESC0201_L
C6, C14, C20, C21: 4.7µF; NORDIC_NRF_3_RESC0201_L
C9: 820pF; NORDIC_NRF_3_RESC0201_L
C10, C13, C22: N.C.; NORDIC_NRF_3_RESC0201_L
C11: 100pF; NORDIC_NRF_3_RESC0201_L
C15: 1.0µF; NORDIC_NRF_3_RESC0201_L
C16: 47nF; NORDIC_NRF_3_RESC0201_L
C23: 0.1uF; GRM011R60J152KE01L_1_0201
C24, C39: 10uF; NORDIC_NRF_3_RESC0201_L
C25, C33: 22uF; NORDIC_NRF_3_RESC0201_L
C37: 1uF; GRM011R60J152KE01L_1_0201
C38: 1uF; GRM011R60J152KE01L_2_CAPC0201X13N
IC1: BQ25180YBGR; BQ25180YBGR_BGA8C40P2X4_100X155X50
IC3: BMA421; BMA423_BMA423
IC9: RT6160AWSC; RT6160AWSC_BGA15C40P3X5_140X230X60
J2: TC2030-IDC; TC2030-IDC_TC2030IDC
L1: 3.9nH; NORDIC_NRF_2_RESC0402_L
L2: 10µH; NORDIC_NRF_2_RESC0402_L
L3: 15nH; NORDIC_NRF_2_RESC0402_L
L7: FTC252012SR47MBCA; MLP2016SR47MT0S1_INDC2016X100N
R2, R3, R4: 0; CPF0201D7K68C1_0201
R9: 10K; CPF0201D7K68C1_0201
R17, R18: 3K3; CPF0201D7K68C1_0201
TP_3.3V, TP_3V3: HECTOR_WATCH_1_TPTP20R; HECTOR_WATCH_1_TP20R
TP_GND: HECTOR_WATCH_1_TPTP20R; HECTOR_WATCH_1_TP20R
TP_RESET: HECTOR_WATCH_1_TPTP20R; HECTOR_WATCH_1_TP20R
TP_SCL: HECTOR_WATCH_1_TPTP20R; HECTOR_WATCH_1_TP20R
TP_SDA: HECTOR_WATCH_1_TPTP20R; HECTOR_WATCH_1_TP20R
TP_SWDCLK: HECTOR_WATCH_1_TPTP20R; HECTOR_WATCH_1_TP20R
TP_SWDIO: HECTOR_WATCH_1_TPTP20R; HECTOR_WATCH_1_TP20R
TP_SWO: HECTOR_WATCH_1_TPTP20R; HECTOR_WATCH_1_TP20R
TP_VREG: HECTOR_WATCH_1_TPTP20R; HECTOR_WATCH_1_TP20R
U1: NRF52840_QF; NORDIC_NRF_4_AQFN50P700X700X85_HS-74N
X1: 32MHz; NORDIC_NRF_BT-XTAL_2016_N
X2: 32.768kHz; NORDIC_NRF_1_XTAL_3215_N

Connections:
3V3: C6.1, C7.1, C8.1, C12.1, C14.1, C19.1, C25.1, C33.1, IC3.3 (VDDIO), IC3.7 (VDD), IC3.10 (CSB), IC9.E2 (VOUT_1), IC9.E3 (VOUT_2), J2.1, R17.1, R18.1, TP_3.3V.TP, TP_3V3.TP, U1.P$A22 (VDD), U1.P$AD14 (VDD), U1.P$AD23 (VDD), U1.P$B1 (VDD), U1.P$W1 (VDD), U1.P$Y2 (VDDH); also elsewhere on the board
ALERT: U1.P$J24 (P0.10/NFC2); also elsewhere on the board
D+: U1.P$AD6 (D+); also elsewhere on the board
D-: U1.P$AD4 (D-); also elsewhere on the board
DEC1: C5.1, U1.P$C1 (DEC1)
DEC3: C11.1, U1.P$D23 (DEC3)
DEC4_6: C10.1, C15.1, C16.1, L3.2, U1.P$B5 (DEC4), U1.P$E24 (DEC6)
EPD_BUSY: U1.P$AD12 (P0.17); also elsewhere on the board
EPD_CS: U1.P$K2 (P0.05/AIN3); also elsewhere on the board
EPD_DC: U1.P$AD10 (P0.15); also elsewhere on the board
EPD_RST: U1.P$AC11 (P0.16); also elsewhere on the board
GND: C1.2, C2.2, C3.2, C4.2, C5.2, C6.2, C7.2, C8.2, C9.2, C10.2, C11.2, C12.2, C13.2, C14.2, C15.2, C16.2, C17.1, C18.1, C19.2, C20.2, C21.2, C22.2, C23.1, C24.1, C25.2, C33.2, C37.1, C38.1, C39.2, IC1.D2 (GND), IC3.8 (GNDIO), IC3.9 (GND), IC9.B1 (VSEL), IC9.C1 (AGND), IC9.C2 (PGND_1), IC9.C3 (PGND_2), J2.3, J2.5, R3.1, R9.1, TP_GND.TP, U1.P$74 (VSS_PAD), U1.P$75 (VSS_PAD), U1.P$76 (VSS_PAD), U1.P$77 (VSS_PAD), U1.P$78 (VSS_PAD), U1.P$79 (VSS_PAD), U1.P$80 (VSS_PAD), U1.P$81 (VSS_PAD), U1.P$82 (VSS_PAD), U1.P$83 (VSS_PAD), U1.P$84 (VSS_PAD), U1.P$85 (VSS_PAD), U1.P$86 (VSS_PAD), U1.P$87 (VSS_PAD), U1.P$88 (VSS_PAD), U1.P$89 (VSS_PAD), U1.P$90 (VSS_PAD), U1.P$B7 (VSS), U1.P$F23 (VSS_PA), X1.2, X1.4; also elsewhere on the board
HAPTIC_EN: U1.P$U1 (P0.12); also elsewhere on the board
IMU_INT1: IC3.5 (INT1), U1.P$N1 (P0.08)
IMU_INT2: IC3.6 (INT2), U1.P$P2 (P1.08)
LX1: IC9.B2 (SW1_1), IC9.B3 (SW1_2), L7.1
LX2: IC9.D2 (SW2_1), IC9.D3 (SW2_2), L7.2
MOSI: U1.P$B13 (P0.03/AIN1); also elsewhere on the board
unnamed: IC3.1 (SDO), R3.2
unnamed: IC1.D1 (TS/MR), R9.2
unnamed: IC9.D1 (SCL), R4.2
unnamed: IC9.E1 (SDA), R2.2
unnamed: C20.1, U1.P$AC5 (DEC3V3)
unnamed: L2.1, U1.P$B3 (DCC)
unnamed: L2.2, L3.1
unnamed: C13.1, U1.P$A18 (DEC2)
unnamed: C9.1, U1.P$N24 (DEC5)
unnamed: C3.1, L1.1, U1.P$H23 (ANT)
unnamed: C2.1, U1.P$A23 (XC2), X1.3
unnamed: C1.1, U1.P$B24 (XC1), X1.1
P0.00/XL1: C17.2, U1.P$D2 (P0.00/XL1), X2.1
P0.01/XL2: C18.2, U1.P$F2 (P0.01/XL2), X2.2
P0.04: U1.P$J1 (P0.04/AIN2)
P0.09: U1.P$L24 (P0.09/NFC1)
P0.13: U1.P$AD8 (P0.13); also elsewhere on the board
P0.14: U1.P$AC9 (P0.14); also elsewhere on the board
P0.19: U1.P$AC15 (P0.19)
P0.20: U1.P$AD16 (P0.20)
P0.21: U1.P$AC17 (P0.21)
P0.22: U1.P$AD18 (P0.22)
P0.23: U1.P$AC19 (P0.23)
P0.24: U1.P$AD20 (P0.24)
P0.25: U1.P$AC21 (P0.25)
P0.26: U1.P$G1 (P0.26)
P0.27: U1.P$H2 (P0.27)
P0.28: U1.P$B11 (P0.28/AIN4)
P0.29: U1.P$A10 (P0.29/AIN5)
P0.30: U1.P$B9 (P0.30/AIN6)
P0.31: U1.P$A8 (P0.31/AIN7)
P1.01: U1.P$Y23 (P1.01); also elsewhere on the board
P1.02: U1.P$W24 (P1.02); also elsewhere on the board
P1.03: U1.P$V23 (P1.03)
P1.04: U1.P$U24 (P1.04)
P1.05: U1.P$T23 (P1.05)
P1.06: U1.P$R24 (P1.06)
P1.07: U1.P$P23 (P1.07)
P1.09: U1.P$R1 (P1.09)
P1.10: U1.P$A20 (P1.10)
P1.11: U1.P$B19 (P1.11)
P1.12: U1.P$B17 (P1.12)
P1.13: U1.P$A16 (P1.13)
P1.14: U1.P$B15 (P1.14)
P1.15: U1.P$A14 (P1.15)
PMIC_INT: IC1.A1 (!INT), U1.P$T2 (P0.11)
RESET: J2.6, TP_RESET.TP, U1.P$AC13 (P0.18/RESET)
RF: ANT1.1 (FEED), C4.1, C22.1, L1.2
SCK: U1.P$A12 (P0.02/AIN0); also elsewhere on the board
SCL: IC1.B1 (SCL), IC3.12 (SCX), R4.1, R17.2, TP_SCL.TP, U1.P$M2 (P0.07); also elsewhere on the board
SDA: IC1.C1 (SDA), IC3.2 (SDX), R2.1, R18.2, TP_SDA.TP, U1.P$L1 (P0.06); also elsewhere on the board
SWDCLK: J2.4, TP_SWDCLK.TP, U1.P$AC24 (SWDIO)
SWDIO: J2.2, TP_SWDIO.TP, U1.P$AA24 (SWDCLK)
SWO: TP_SWO.TP, U1.P$AD22 (P1.00)
VBAT: C37.2, IC1.C2 (BAT); also elsewhere on the board
VBUS: C21.1, C38.2, IC1.A2 (IN), U1.P$AD2 (VBUS); also elsewhere on the board
VREG: C23.2, C24.2, C39.1, IC1.B2 (SYS), IC9.A1 (EN), IC9.A2 (VIN_1), IC9.A3 (VIN_2), TP_VREG.TP

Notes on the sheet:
LiPo Charger
IMU
DC/DC
SWD

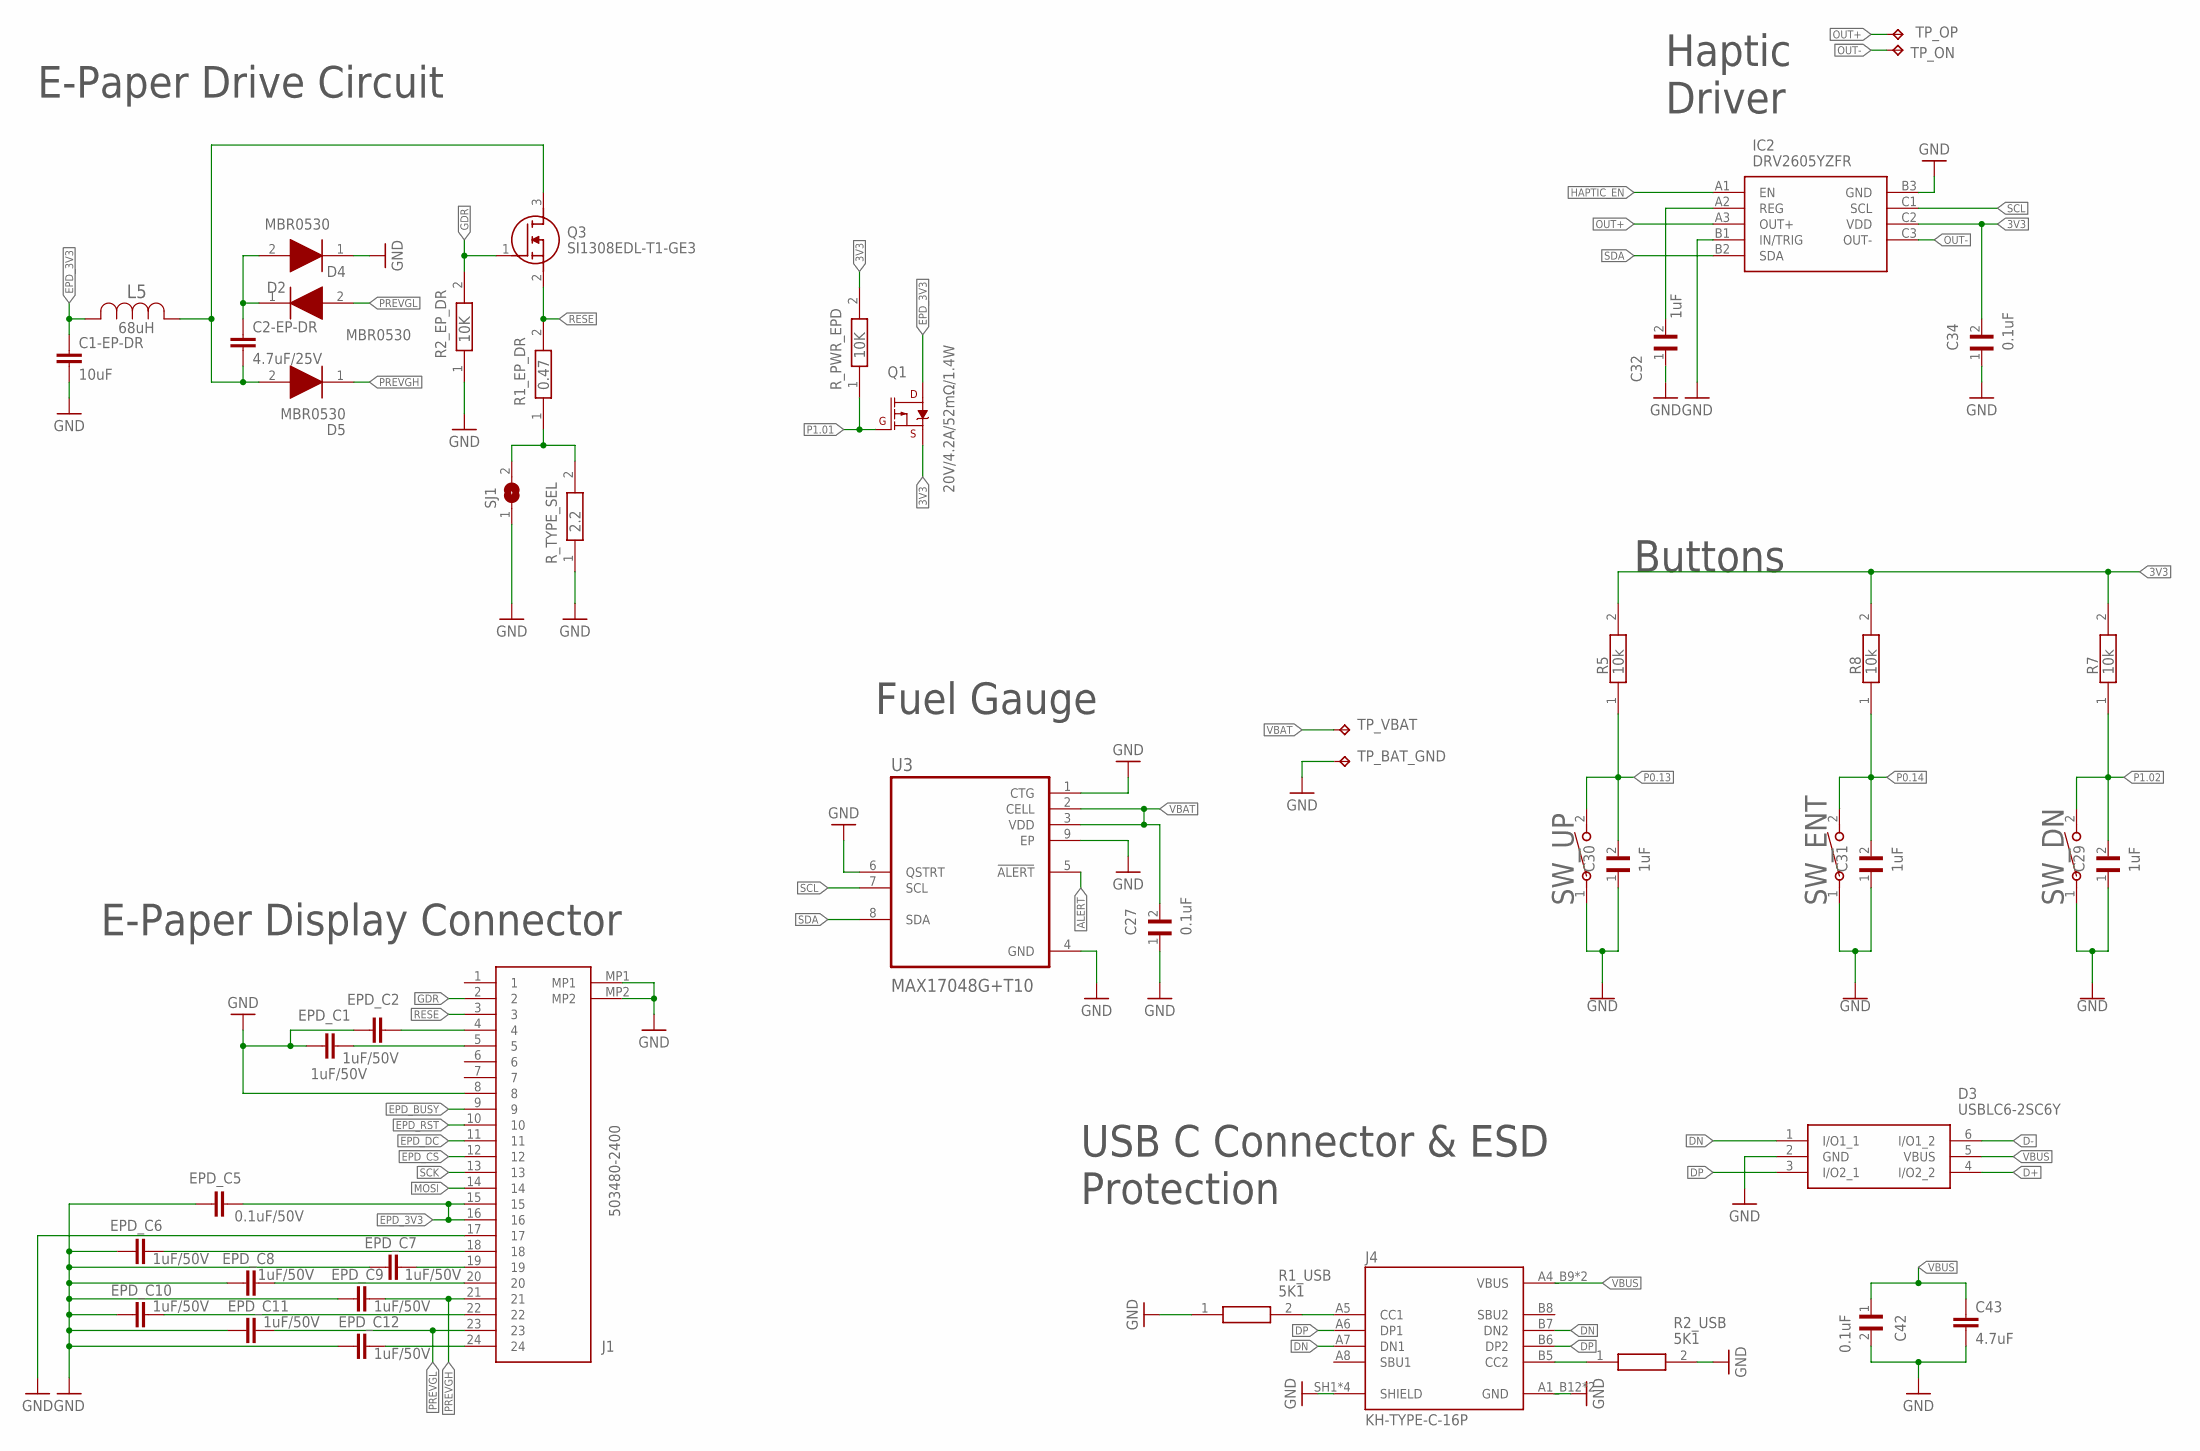
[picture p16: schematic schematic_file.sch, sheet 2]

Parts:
C1-EP-DR: 10uF; NORDIC_NRF_3_RESC0201_L
C2-EP-DR: 4.7uF/25V; NORDIC_NRF_3_RESC0201_L
C27, C34, C42: 0.1uF; GRM011R60J152KE01L_1_0201
C29, C30, C31, C32: 1uF; GRM011R60J152KE01L_1_0201
C43: 4.7uF; NORDIC_NRF_3_RESC0201_L
D2, D4, D5: MBR0530; ESP32_C6_LIBRARY_5_SOD3716X135N
D3: USBLC6-2SC6Y; ESP32_C6_LIBRARY_3_SOT95P280X145-6N
EPD_C1, EPD_C2, EPD_C6, EPD_C7, EPD_C8, EPD_C9, EPD_C10, EPD_C11, EPD_C12: 1uF/50V; NORDIC_NRF_3_RESC0201_L
EPD_C5: 0.1uF/50V; NORDIC_NRF_3_RESC0201_L
IC2: DRV2605YZFR; DRV2605YZFR_BGA9C50P3X3_144X144X62
J1: 503480-2400; 503480-2400_5034802400
J4: KH-TYPE-C-16P; KH-TYPE-C-16P_KINGHELM_KH-TYPE-C-16P
L5: 68uH; ESP32_C6_LIBRARY_2_IND_4828-WE-TPC_WRE
Q1: 20V/4.2A/52mΩ/1.4W; ESP32_C6_LIBRARY_4_ESP32_C6_LIBRARY_4_ESP32_C6_LIBRARY_4_ES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
Q3: SI1308EDL-T1-GE3; ESP32_C6_LIBRARY_6_SOT65P210X110-3N
R1_EP_DR: 0.47; CPF0201D7K68C1_0201
R1_USB, R2_USB: 5K1; CPF0201D7K68C1_0201
R2_EP_DR: 10K; CPF0201D7K68C1_0201
R5, R7, R8: 10k; CPF0201D7K68C1_0201
R_PWR_EPD: 10K; CPF0201D7K68C1_0201
R_TYPE_SEL: 2.2; CPF0201D7K68C1_0201
SJ1: ESP32_C6_LIBRARY_7_JUMPER_SJ
SW_DN: 2025-10-22_07-23-44_LIBRARY_EVP-AKE31ASW_EVP-AKE3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; 2025-10-22_07-23-44_LIBRARY_SW_EVP-AKE31A_PAN
SW_ENT: 2025-10-22_07-23-44_LIBRARY_EVP-AKE31ASW_EVP-AKE3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; 2025-10-22_07-23-44_LIBRARY_SW_EVP-AKE31A_PAN
SW_UP: 2025-10-22_07-23-44_LIBRARY_EVP-AKE31ASW_EVP-AKE3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; 2025-10-22_07-23-44_LIBRARY_SW_EVP-AKE31A_PAN
TP_BAT_GND: HECTOR_WATCH_1_TPTP20R; HECTOR_WATCH_1_TP20R
TP_ON: HECTOR_WATCH_1_TPTP20R; HECTOR_WATCH_1_TP20R
TP_OP: HECTOR_WATCH_1_TPTP20R; HECTOR_WATCH_1_TP20R
TP_VBAT: HECTOR_WATCH_1_TPTP20R; HECTOR_WATCH_1_TP20R
U3: MAX17048G+T10; ESP32_C6_LIBRARY_SON50P200X200X80-9N

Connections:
3V3: C34.2, IC2.C2 (VDD), Q1.2 (S), R5.2, R7.2, R8.2, R_PWR_EPD.2; also elsewhere on the board
ALERT: U3.5 (!ALERT); also elsewhere on the board
D+: D3.4 (I/O2_2); also elsewhere on the board
D-: D3.6 (I/O1_2); also elsewhere on the board
DN: D3.1 (I/O1_1), J4.A7 (DN1), J4.B7 (DN2)
DP: D3.3 (I/O2_1), J4.A6 (DP1), J4.B6 (DP2)
EPD_3V3: C1-EP-DR.1, EPD_C5.2, J1.15, J1.16, L5.2, Q1.3 (D)
EPD_BUSY: J1.9; also elsewhere on the board
EPD_CS: J1.12; also elsewhere on the board
EPD_DC: J1.11; also elsewhere on the board
EPD_RST: J1.10; also elsewhere on the board
GDR: J1.2, Q3.1 (G), R2_EP_DR.2
GND: C1-EP-DR.2, C27.1, C29.1, C30.1, C31.1, C32.1, C34.1, C42.2, C43.2, D3.2 (GND), D4.1 (K), EPD_C1.1, EPD_C2.1, EPD_C5.1, EPD_C6.1, EPD_C7.1, EPD_C8.1, EPD_C9.1, EPD_C10.1, EPD_C11.1, EPD_C12.1, IC2.B1 (IN/TRIG), IC2.B3 (GND), J1.8, J1.17, J1.MP1, J1.MP2, J4.A1_B12 (GND), J4.A12_B1 (GND), J4.SH1 (SHIELD), J4.SH2 (SHIELD), J4.SH3 (SHIELD), J4.SH4 (SHIELD), R1_USB.1, R2_EP_DR.1, R2_USB.2, R_TYPE_SEL.1, SJ1.1, SW_DN.1, SW_ENT.1, SW_UP.1, TP_BAT_GND.TP, U3.1 (CTG), U3.4 (GND), U3.6 (QSTRT), U3.9 (EP); also elsewhere on the board
HAPTIC_EN: IC2.A1 (EN); also elsewhere on the board
MOSI: J1.14; also elsewhere on the board
unnamed: R1_EP_DR.1, R_TYPE_SEL.2, SJ1.2
unnamed: C2-EP-DR.2, D5.2 (A), L5.1, Q3.3 (D)
unnamed: C2-EP-DR.1, D2.1 (K), D4.2 (A)
unnamed: EPD_C2.2, J1.4
unnamed: EPD_C1.2, J1.5
unnamed: J4.B5 (CC2), R2_USB.1
unnamed: C32.2, IC2.A2 (REG)
unnamed: EPD_C6.2, J1.18
unnamed: EPD_C7.2, J1.19
unnamed: EPD_C8.2, J1.20
unnamed: EPD_C10.2, J1.22
unnamed: EPD_C12.2, J1.24
unnamed: J4.A5 (CC1), R1_USB.2
OUT+: IC2.A3 (OUT+), TP_OP.TP
OUT-: IC2.C3 (OUT-), TP_ON.TP
P0.13: C30.2, R5.1, SW_UP.2; also elsewhere on the board
P0.14: C31.2, R8.1, SW_ENT.2; also elsewhere on the board
P1.01: Q1.1 (G), R_PWR_EPD.1; also elsewhere on the board
P1.02: C29.2, R7.1, SW_DN.2; also elsewhere on the board
PREVGH: D5.1 (K), EPD_C9.2, J1.21
PREVGL: D2.2 (A), EPD_C11.2, J1.23
RESE: J1.3, Q3.2 (S), R1_EP_DR.2
SCK: J1.13; also elsewhere on the board
SCL: IC2.C1 (SCL), U3.7 (SCL); also elsewhere on the board
SDA: IC2.B2 (SDA), U3.8 (SDA); also elsewhere on the board
VBAT: C27.2, TP_VBAT.TP, U3.2 (CELL), U3.3 (VDD); also elsewhere on the board
VBUS: C42.1, C43.1, D3.5 (VBUS), J4.A4_B9 (VBUS), J4.A9_B4 (VBUS); also elsewhere on the board

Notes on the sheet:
E-Paper Drive Circuit
E-Paper Display Connector
Fuel Gauge
Haptic Driver
Buttons
USB C Connector & ESD Protection

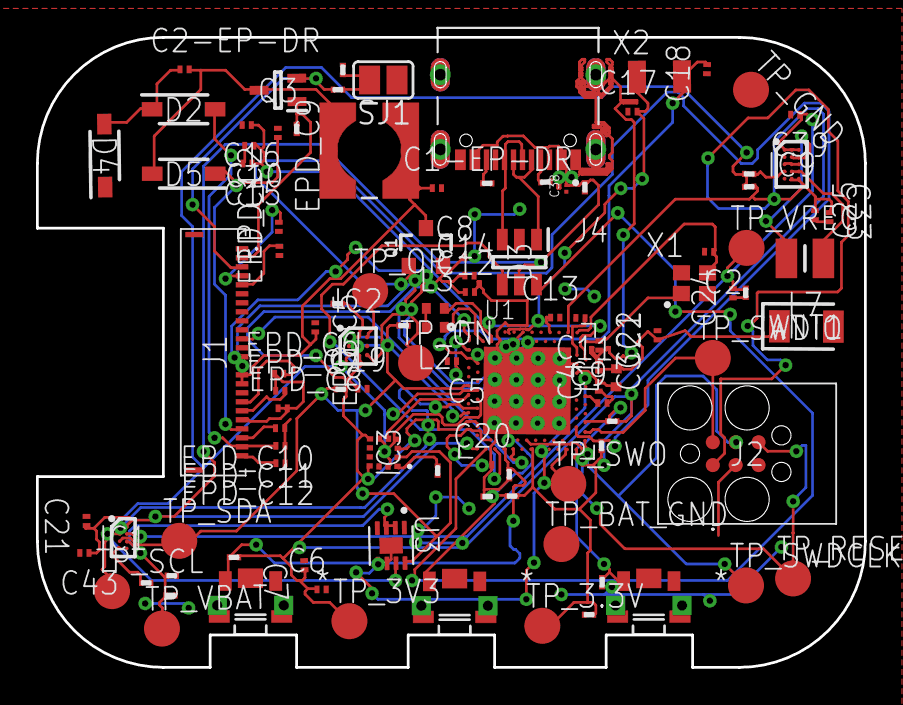
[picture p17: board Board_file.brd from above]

Board: 2 copper layers, 46.0 x 35.0 mm, 105 parts (0 on the bottom side), 70 nets.

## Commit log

2026-04-22 Enhance README with project details and BOM
    Add block diagram and Bill of Materials to README
2026-04-22 Added 3DPCB design, 3DPCB exploded-view and 2DPCB, gerbers
    [Board_file.brd, InkTime3D - FinalAssembly.f3z, InkTime3D - exploded view.f3z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]
2026-04-22 Added schematic print-out
2026-04-22 Updated README with comprehensive project details
    Updated the README to include detailed project documentation, including hardware functionality, block diagrams, pinout table, BOM, design details, and renders.

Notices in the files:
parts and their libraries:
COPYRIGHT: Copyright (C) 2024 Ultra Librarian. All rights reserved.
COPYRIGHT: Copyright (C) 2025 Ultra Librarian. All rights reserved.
